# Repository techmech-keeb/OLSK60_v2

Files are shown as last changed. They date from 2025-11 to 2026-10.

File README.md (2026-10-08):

# OLSK60 v2
60% OrthoLinear Keyboard w/ TrackPoint – Designed for Standard Keycap Compatibility

> **この説明はファームウェア v3.0.0 以降向けです。**
> 旧版（v2.x）をお使いの方は、[v2.0.3 時点の説明](https://github.com/techmech-keeb/OLSK60_v2/tree/v2.0.3)をご覧ください。

> **v3.0.0 の公開（2026年10月8日）より前に購入された方へ:** お手元のキーボードには旧版（v2.x）のファームウェアが書き込まれています。**[firmware/README.md](firmware/README.md) の手順で v3 に更新してください。**本リポジトリの説明は v3 を前提にしています。どちらが書き込まれているかわからない場合も、更新して問題ありません（キーボードに保存された設定は初期化されます）。

OLSK60 v2 キーボード外観写真

## 概要
OLSK60 v2は、標準的なキーキャップセットに対応した、60%サイズの格子配列キーボードです。  
トラックポイントを搭載しているため、マウス操作もこの一台で完結します。  
また、GH60互換ケースに対応しており、お好みのキーキャップやケースと自由に組み合わせて、自分だけのカスタマイズを楽しめます。  
見た目も使い心地も、あなた好みに仕上げてください。

> **モデルについて:** 現在販売中のモデルは **v2.1** です。出荷時は **5-Split Space** レイアウトで、同梱のトッププレートに付け替えることで 3-Split Space／6.25U Space にも変更できます。旧モデル **v2** は 3-Split Space および 6.25U Space のみに対応しています。
>
> **ファームウェア（v3）は、機能はどれも同じで、出荷時のキーマップ（プリセット）だけが 2 通り**あります。5-Split Space 用と 3-Split Space 用で、**お使いのトッププレートに合うプリセットを選べば、書き込んだあと調整なしで使えます**。どちらを書き込んでも動作し、キー配置は Vial でいつでも変更できます。

### 主な特徴
- 格子配列60キー
- トラックポイント搭載
- GH60互換ケース対応
- Vial 対応（キーボード定義はファームウェア内蔵）
- 5-Split Space レイアウトで出荷（他のスペース列は対応ファームウェアを書き込んで使用）
- ホットスワップスイッチソケット採用
- スタビライザー実装済み

### 仕様

| 項目 | 内容 |
|---|---|
| 配列 | 直交（格子）配列 60キー、60%サイズ |
| 接続 | USB Type-C |
| MCU | RP2040（UF2 形式でファームウェア書き込み） |
| キーマップ | 5レイヤー、設定ツール（Vial）で編集可能 |
| 同時押し | 6キーまで（標準的な USB キーボードと同じ） |
| ポインティングデバイス | トラックポイント（押し下げクリック対応、オートマウスレイヤー機能） |
| ロータリーエンコーダ | オプション（右上に取り付け可能） |
| LED インジケーター | 1個（レイヤー・設定状態を色で表示） |
| スイッチ | ホットスワップソケット（MX互換） |
| ケース | GH60 互換 |
| キーキャップ | 標準的なキーキャップセットに対応 |

### 出荷時のキー配列（レイヤー0）

OLSK60 レイヤー0（基本レイヤー）のキー配列図

レイヤー構成の詳細は[キーボード操作ガイド](docs/OLSK60_user_guide.md)をご参照ください。

## ドキュメント

> **初めての方へ:** キットを購入された方は、ビルドガイド → キーボード操作ガイド の順にお読みください。

- [ビルドガイド](docs/buildguide.md) — キットの組み立て手順
- [キーボード操作ガイド](docs/OLSK60_user_guide.md) — レイヤー構成・各機能の使い方
- [マウス機能操作マニュアル](docs/OLSK60_mouse_manual.md) — トラックポイントの速度を自分好みに調整する方法
- [FAQ（よくある質問）](docs/faq.md) — モデルの見分け方・設定ツールの選び方など
- [3Dデータ](cad/)
  - [トラックポイントカバー](cad/trackpoint-cover/) - カスタマイズ用のSTEP/STLファイル

## ファームウェア
コンパイル済みファームウェアおよび更新手順は [`firmware/README.md`](firmware/README.md) にて公開しています。

- v3 は **Vial 専用**です（Remap / VIA には対応していません）。
- ファームウェアの**機能は共通**です。ファイルが 2 つあるのは**出荷時のキーマップ（プリセット）の違い**だけで、`5split` / `3split` からお使いのスペース列に合う方を選ぶと、そのまま調整なしで使えます。
- **v3.0.0 の公開（2026年10月8日）より前に購入された方は、v3 に更新してください**（旧版 v2.x が書き込まれています）。

## 購入




| 販売先 | 販売形態 | リンク |
|---|---|---|
| BOOTH | Techmech keys 直営オンラインショップ | [商品ページ](https://techmech.booth.pm/items/5896343) |
| 遊舎工房 | 委託販売（店頭 & オンライン） | [商品ページ](https://shop.yushakobo.jp/products/11324) |

商品に関するお問い合わせは、ご購入先を問わず **Techmech keys** までお願いいたします。

## ライセンス
このプロジェクトは[MITライセンス](LICENSE)の下で公開されています。

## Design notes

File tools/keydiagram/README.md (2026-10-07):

# keydiagram — 操作マニュアル用キー配置図ジェネレータ

`docs/images/` のキー配置図（layer0-base.svg 等）と**完全に同一の様式**で
新しい図を生成するツール。データとスタイルを分離して管理する。

```text
tools/keydiagram/
├─ generate.py        # SVG ジェネレータ（要 python3 + PyYAML）
├─ render_png.mjs     # SVG → PNG(2x) レンダラ（要 Node + Playwright + Chromium）
├─ fetch_fonts.py     # PNG 描画用 Noto Sans JP ウェブフォント取得（初回のみ）
├─ verify_style.py    # 様式回帰テスト（layer0 図をバイト一致で再現できるか）
├─ sync_parts.py      # 共通部品を各図へ複製・検証
├─ parts/
│  └─ mx-switch.svg   # スイッチ正面図の部品マスター
├─ layouts/
│  └─ olsk60.yaml     # 表示レイアウト（キー座標・出荷時刻印）＋ハードウェア注記
└─ diagrams/
   ├─ layer0-base.yaml        # 既存図の再現スペック（回帰テスト基準）
   ├─ piano-mode.yaml         # サウンド機能・ピアノモード音階配置図
   └─ keycap-sizes-*.yaml     # キーキャップサイズガイド（5split/3split/625u）
```

## 使い方

```bash
cd tools/keydiagram
python3 generate.py diagrams/piano-mode.yaml          # SVG を docs/images/ へ
python3 fetch_fonts.py                                # 初回のみ（PNG 用フォント）
python3 generate.py diagrams/piano-mode.yaml --png    # PNG (1936x1000) も生成
python3 verify_style.py                               # 様式回帰テスト
```

## データモデル

3種類の情報を分けて管理する。

1. **表示レイアウト**（`layouts/olsk60.yaml` の `keys:`）
   キーの座標（1u = 60px）・幅・出荷時の刻印。既存図から抽出し、
   製品の物理レイアウト定義と突合済み。
   分割位置（スペース分割・下段オプション）は出荷時キーキャップ構成に統合した
   「表示用」であり、物理マトリクスと 1:1 ではない点に注意。
2. **ハードウェア注記**（同ファイルの `hardware:`）
   TrackPoint マーカーやロータリーエンコーダ凡例など、
   キーマトリクスに現れない要素。
3. **図スペック**（`diagrams/*.yaml`）
   バッジ・タイトル・LED 表示・キーごとの強調/ラベル差し替え・凡例・脚注。
   キーは表示レイアウトの `id` で参照する。

### 図スペックの主な書式

```yaml
layout: olsk60                      # layouts/<name>.yaml を参照
badge: {text: サウンド, color: "#2f66c4"}
title: ピアノモード（音階配置）
note: 右上の補足テキスト
led: {text: 青}                     # 「LED: 」+ 全角テキスト（ドット位置は自動計算）
defaults: base                      # base=出荷時配色 / disabled=全キー薄灰
styles:                             # 図ローカルのキースタイル定義
  white-key: {fill: "#ffffff", stroke: "#2f66c4", label: "#212529", sub: "#868e96"}
keys:                               # id ごとの上書き
  a: {style: white-key, lines: [C4, ド], sub: A}   # lines=2行表示, sub=上部小ラベル
  enter: {style: fx-key, label: Enter, size: 11}   # label=1行表示
encoder:                            # エンコーダ凡例（最大3行＋脚注）
  lines: ["時計回り: ...", "反時計回り: ...", "..."]
  footnote: ※ ...
legend:                             # 下部凡例（row: 2 で2段目、style 省略で文字のみ）
  - {x: 340, style: white-key, text: 白鍵に相当（音階）}
```

### 最下段バリアントとサイズ表示モード

最下段のスペースバー構成（5-Split / 3-Split / 6.25U）は `layouts/olsk60.yaml`
の `variants:` に定義してある（上4段は共通）。図スペックで選択・表示する。

```yaml
variant: 3-split          # 最下段を 3-Split に差し替える（未指定＝5-Split）
label_mode: size          # 全キーに「刻印名（上）＋幅 1.25U（下）」を表示
legend_mode: sizes        # サイズ別の必要数を自動集計して下部に凡例表示
legend_title: ...         # サイズ凡例の見出し（省略可）
legend_footnote: ...      # サイズ凡例の脚注（省略可）
hide_trackpoint: true     # サイズ表では TrackPoint マーカーを隠す
size_palette:             # サイズ→配色（label_mode: size 時に適用）
  1U:    {fill: "#ffffff", stroke: "#c3c9cf"}
  1.25U: {fill: "#dbeafe", stroke: "#4d82c4"}
  # ...
```

`variant` を増やすときは `layouts/olsk60.yaml` の `variants:` に
`replace_y`（差し替える行）とその行のキー一覧を足す。座標の出典は
製品のキーボード定義（レイアウトオプションの選択肢）。

## 共通部品（parts/）

複数の図に登場する部品（キースイッチ等）は `parts/` にマスターを置き、
`sync_parts.py` で各図へ複製する。

```bash
python3 sync_parts.py           # マスターの内容を各図へ反映
python3 sync_parts.py --check   # ズレがないか検証のみ
```

GitHub 上で表示される SVG は外部ファイルを参照できない（`<use href="other.svg#id">`
が効かない）ため、部品は各図にインライン複製する必要がある。複製先は
`<!-- parts:<部品名>:begin -->` 〜 `<!-- parts:<部品名>:end -->` で囲んだ範囲で、
**この中は手で編集しない**（マスターを直して同期する）。

現在の部品:

| 部品 | マスター | 複製先 |
|---|---|---|
| `mx-switch-front` | `parts/mx-switch.svg` | `switch-pins.svg` / `switch-mount.svg` / `build-exploded.svg` |

スイッチ部品の形状は `docs/images/cherry-mx-switch-views.svg`（三面図）の正面図から
取り出したもので、縮尺は **6px = 1mm**。寸法の根拠は
`docs/reference/cherry-mx-switch-spec.md`。ピンは図ごとに描き分けるため部品に含めない
（曲がったピンの図示などに使うため）。

## 様式を変えないためのルール

- ジェネレータや `layouts/olsk60.yaml` を変更したら `verify_style.py` を実行し、
  既存の `docs/images/layer0-base.svg` をバイト一致で再現できることを確認する。
- 新しい配色を増やすときは、既存図のパレット（`generate.py` の `STYLES` と
  既存 diagram の `styles:`）に馴染む色を選ぶ。

## PNG 描画の前提

- Node.js + Playwright（`npm i -g playwright` 済み環境か `npx playwright`）と
  Chromium が必要。ヘッドレス Chromium の `--screenshot` を直接使うと
  ウィンドウ枠ぶんビューポートが欠けるため、Playwright で正確な
  ビューポート（968x500, deviceScaleFactor=2）を指定している。
- 文字は Noto Sans JP。システムに無い環境向けに `fetch_fonts.py` が
  Google Fonts から woff2 を `fonts/`（gitignore 済み）へ取得し、
  レンダラが @font-face で適用する。
- 生成 PNG は既存図と同じ 1936x1000 / 8-bit RGB に正規化される。

## 将来の汎用化メモ

- 他キーボードは `layouts/<name>.yaml` を追加すれば同じ図スペック書式で使える。
  キーボード定義の座標データ（x / y / w）から座標を起こし、
  1u=60px・セル内 3px オフセットで px 化する（`x_px = 3 + 60 * x_u`）。
- 既存の他の図（layer1/2/3 等）も diagram スペック化すれば再生成可能になる。

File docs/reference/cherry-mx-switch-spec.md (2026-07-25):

# Cherry MX スイッチ 寸法リファレンス

単位はすべて mm。元図（Cherry MX データシートの DIMENSIONS / MOUNTING OPTIONS）から読み取った値と、
一般的な MX 互換寸法として補った値を分けて記載する。

| 項目 | 内容 |
|---|---|
| 出典 | Cherry MX データシート（DIMENSIONS / MOUNTING OPTIONS 図）|
| 最終確認日 | 2026-07-24 |
| 用途 | OLSK60 のビルドガイド（スイッチ・プレート・キーキャップの寸法説明）の根拠 |
| 図 | [`../images/cherry-mx-switch-views.svg`](../images/cherry-mx-switch-views.svg)（本書の数値を作図したもの。6px = 1mm）|

> **Status: Reviewed** — §1〜§4 は元図の記載値。§5 と一部の外形値は一般的な MX 互換寸法として補った参考値（§6 参照）。
>
> 「Cherry MX」は Cherry 社の商標。本書は MX 互換スイッチ全般の寸法目安として参照するものであり、
> OLSK60 に特定ブランドのスイッチが同梱・指定されることを意味しない。

## 1. 高さ方向（積み上げ）

| 部位 | 寸法 | 備考 |
|---|---|---|
| ステム突出（ハウジング上面〜ステム頂点） | 3.6 | 未押下時 |
| ハウジング全高 | 11.6 | トップ上面〜ボトム下端 |
| └ うち下部ハウジング（フランジ下面より下） | 5.0 | 11.6 の内訳 |
| ピン突出 | 3.3 | ボトム下端より下 |
| **全高** | **18.5** | 3.6 + 11.6 + 3.3 |

## 2. 外形（XY）

| 項目 | 寸法 |
|---|---|
| トップハウジング フランジ外形 | 15.6 × 15.6 |
| 下部ハウジング（プレート穴に入る部分） | 14.0 × 14.0 |
| プレート開口（推奨） | 14.0 × 14.0 |
| キースイッチピッチ | 19.05 |

## 3. マウント条件

| 項目 | 寸法 | 備考 |
|---|---|---|
| プレート厚 | 1.5 | 0.06 ±0.006 in |
| プレート下面までのハウジング長 | 4.8 | 0.197 +0.012 in |
| プレート上面〜ピン先端 | 約 8.1 | 4.8 + 3.3。元図の「< 8」相当 |
| プレート上面〜ステム頂点 | 約 10.2 | 6.6 + 3.6 |

プレートマウントでは 15.6 のフランジがプレート上面に載り、下部ハウジング側面のラッチが
厚さ 1.5 のプレートに噛む。PCB マウント（5 ピン）はこれに位置決めボスとピンが加わる。

## 4. PCB フットプリント

中央ボス中心を原点 (0, 0) とする。X は右、Y は上（＝上面から見た座標）。

| 穴 | 座標 | 径 |
|---|---|---|
| 中央ボス | (0, 0) | φ4.0 |
| 位置決めボス L | (-5.08, 0) | φ1.7 |
| 位置決めボス R | (+5.08, 0) | φ1.7 |
| 端子 1 | (-3.81, +2.54) | φ1.5 |
| 端子 2 | (+2.54, +5.08) | φ1.5 |

3 ピン（プレートマウント）版では位置決めボス 2 つが省かれる。

## 5. ステム（参考値・元図に記載なし）

| 項目 | 寸法 |
|---|---|
| 十字アーム全長 | 約 4.1 |
| 十字スロット幅 | 約 1.35 |
| ステム外形 | 約 5.5 × 5.5 |
| トラベル（フルストローク） | 4.0 |
| アクチュエーションポイント | 2.0（MX Brown / Blue 等） |

## 6. 注記

- 元図で寸法が明示されているのは §1〜§3 と §4 の座標のみ。
- §5 および「下部ハウジング 14.0」「トップ上面 11.6 角」は一般的な MX 互換寸法として補った値であり、
  厳密な設計に使う場合はメーカー図または実測で確認すること。
- インチ値は元図の併記（0.14 / 0.46 / 0.20 / 0.13 / 0.61 in など）に対応する。

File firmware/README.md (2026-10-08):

# OLSK60 ファームウェア

> **このページはファームウェア v3.0.0 以降の案内です。**
> 旧版（v2.x）の案内は [v2.0.3 時点の説明](https://github.com/techmech-keeb/OLSK60_v2/tree/v2.0.3)をご覧ください。
> ファームウェアは[最新リリース](https://github.com/techmech-keeb/OLSK60_v2/releases/latest)からダウンロードできます。

> **v3.0.0 の公開（2026年10月8日）より前に購入された方へ:** 旧版（v2.x）が書き込まれています。**下の手順で v3 に更新してください。** どちらが書き込まれているかわからない場合も、更新して問題ありません（キーボードに保存された設定は初期化されます）。

このフォルダには OLSK60 キーボードのファームウェアに関する案内が含まれています。
本書ではファームウェアの選び方と書き込み手順を扱います。

> 設定ツールの概要・使い方は、[キーボード操作ガイドの「キーマップのカスタマイズ」](../docs/OLSK60_user_guide.md#キーマップのカスタマイズ)に集約しています。

---

## どのファイルを書き込むか

**ファームウェアの機能はどちらも同じです。**配布ファイルが 2 つあるのは、
**出荷時のキーマップ（プリセット）**が 2 通りあるためで、スペース列ごとに
「書き込んだらそのまま使える」配置を用意しています。

| お使いのスペース列 | そのまま使えるプリセット |
|---|---|
| **5 分割**（v2.1 の出荷時） | `OLSK60_v2_firmware_v<バージョン>_Vial_5split.uf2` |
| **3 分割** | `OLSK60_v2_firmware_v<バージョン>_Vial_3split.uf2` |

**どちらを書き込んでも動作します。**キー配置は Vial でいつでも変更できるので、
あとから好みに合わせて割り当て直すこともできます。

> **プリセットが合っていないとどうなるか:** 例えば 3 分割のキーボードに 5 分割用の
> プリセットを書き込むと、Space が物理キーの無い位置に載るため、そのままでは Space が
> 打てません。**Vial で押せる位置に割り当て直せば、そのまま使えます。** 手間を省きたい
>場合は、最初からお使いのスペース列に合うプリセットを選んでください。
>
> 設定ツール側のレイアウト選択は画面表示の切り替えで、打鍵の割り当ては変わりません。
> 書き込んだ直後の Vial の Layout タブは **3-Split Space** 表示です。5 分割のキーボードでは
> 「5-Split Space」を選び直してください（表示だけの設定で、選び直しは保存されます）。

### 設定ツール

v3 は **Vial 専用**です。**Remap / VIA には対応していません。**
キーボード定義はファームウェアに内蔵されているので、定義ファイルの読み込みは不要です。

---

## 書き込み手順

1. キーボードを PC から取り外します。
2. **ESC キーを押しながら** USB ケーブルを接続します。
3. `RPI-RP2` という名前のドライブが表示されます。
4. ダウンロードした `.uf2` ファイルを、そのドライブにコピーします。
5. コピーが終わるとキーボードが自動的に再起動します。
6. Vial で認識されることを確認してください。

> ファームウェアが起動しない状態でも、**ESC キーを押しながら挿せば**この書き込みモードに入れます。

---

## 書き込む前に

- **書き込むと、キーボードに保存された設定（キー配置・マクロ・トラックポイントの速度など）は
  初期化され、出荷時の状態に戻ります。** v3.0.0-rc.4 以降どうしの書き込みであれば、書き込む前に Vial の
  `Save Current Layout` で保存し、書き込み後に `Load Saved Layout` で読み込み直せます。
- ⚠️ **旧版（v2.x）と、v3.0.0-rc.3 以前のテスト版で保存したレイアウトファイル（`.vil`）は読み込まないでください。**
  独自キー（速度設定・サウンド・オートレイヤーなど）の並びが変わっているため、読み込むと
  **別の機能が割り当てられます**。Vial は保存元のキーボードを確認しないので、そのまま書き込まれます。
  これらから移行する場合は、お手数ですが Vial で組み直してください。
- 書き込み中は USB ケーブルを抜かないでください。
- v3 をお使いで問題がない場合、v3 の新しい版への更新は必須ではありません。

## 元に戻すには

旧版（v2.0.3）に戻す場合は、[v2.0.3 のリリース](https://github.com/techmech-keeb/OLSK60_v2/releases/tag/v2.0.3)から `.uf2` をダウンロードし、
上と同じ手順で書き込めば戻ります（このときも設定は初期化されます）。旧版の使い方は
[v2.0.3 時点の説明](https://github.com/techmech-keeb/OLSK60_v2/tree/v2.0.3)をご覧ください。

---

## v3 の主な変更点

旧版（v2.x）からの主な違いです。

- **設定ツールは Vial のみ**になりました（Remap / VIA 非対応）。
- **スペース列ごとに出荷時キーマップ（プリセット）を用意しました**（上記）。機能の違いはありません。
- **同時に押せるキーは 6 キーまで**です。
- **レイヤーが 5 つになりました。** 自由に使える予備のレイヤー（レイヤー3・初期状態は空き）を追加し、
  マウスレイヤーは一番上のレイヤー4になりました。
- **左親指のキーが Scrl キーになりました。** 押している間は Fn レイヤーがそのまま使え、押しながら
  トラックポイントを動かすとスクロールになります。
- **トラックポイントのスクロールが滑らかになりました。** 1 ノッチより細かい単位で送るため、
  ゆっくり動かしたときの追従が改善します。強く操作するほど速く進む調整も既定で有効です
  （設定レイヤーの `T` で切り替えられます）。
- **設定キー（Delete の右）**: 押している間が設定レイヤー（レイヤー2）です。**短くタップしてから押し続ける**と
  予備のレイヤー（レイヤー3）に入ります。
- **設定レイヤーを作り直しました。** 速度・加速・減速・オートレイヤーの時間は、Q / W / E / V で対象を選び、
  ↑ / ↓ で調整します。配置と操作は[キーボード操作ガイド](../docs/OLSK60_user_guide.md#レイヤー2設定レイヤー)を
  ご覧ください。
- **LED の色と光り方を整理しました。** 緑 = オン・完了、赤 = オフ・受け付けない、黄 = 上限、白 = 通常の状態です。点灯 = レイヤー、ゆっくり明滅 = オートレイヤー中、速い明滅 = 値を調整中で区別します（v3.0.1）。
- **出荷時の設定に戻すキー**（設定レイヤーで 5 を 2 秒押し続ける。キー配置は変わりません）を追加しました。
- **トラックポイントの押し込みクリックをオン / オフ**できるようにしました（設定レイヤーの `G`）。
- **調整枠（速度4・速度5）の基本速度の上限を引き上げました。** トラックポイントの反応が弱いと感じる場合は、
  速度5 を選んで基本速度を上げてお使いください。

詳しい操作は[キーボード操作ガイド](../docs/OLSK60_user_guide.md)と
[マウス機能操作マニュアル](../docs/OLSK60_mouse_manual.md)をご覧ください。

---

## ご報告のお願い

お気づきの点は [Issues](https://github.com/techmech-keeb/OLSK60_v2/issues) へお寄せください。
お使いの OS と、どの操作で起きたかを添えていただけると助かります。
うまくいかないときは [FAQ](../docs/faq.md) もご参照ください。

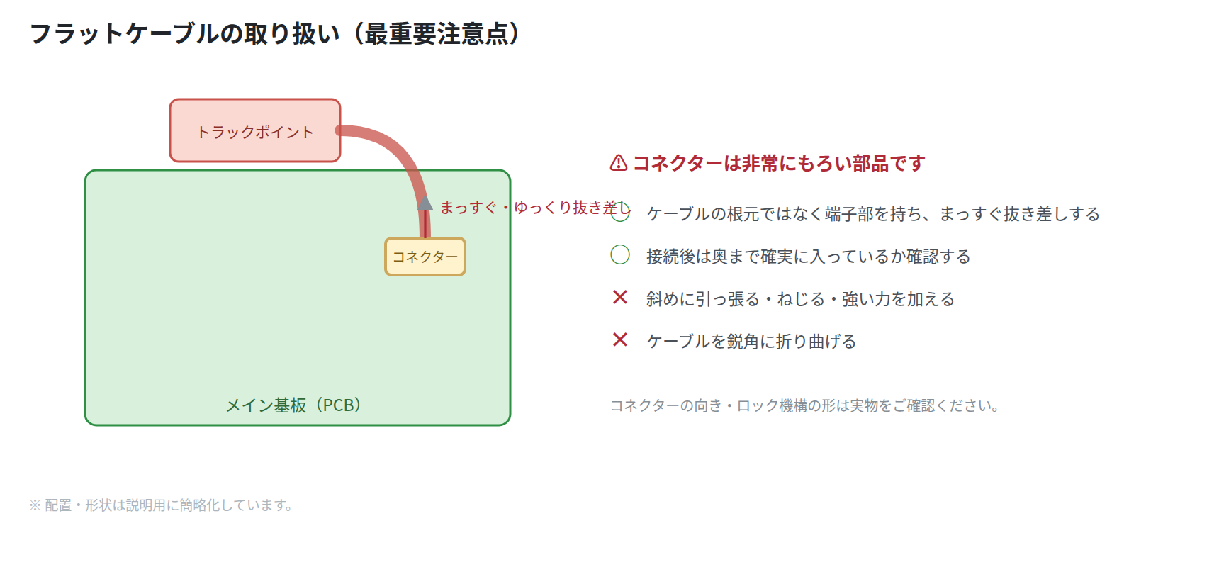
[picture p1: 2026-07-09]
docs/images/flat-cable-handling.png

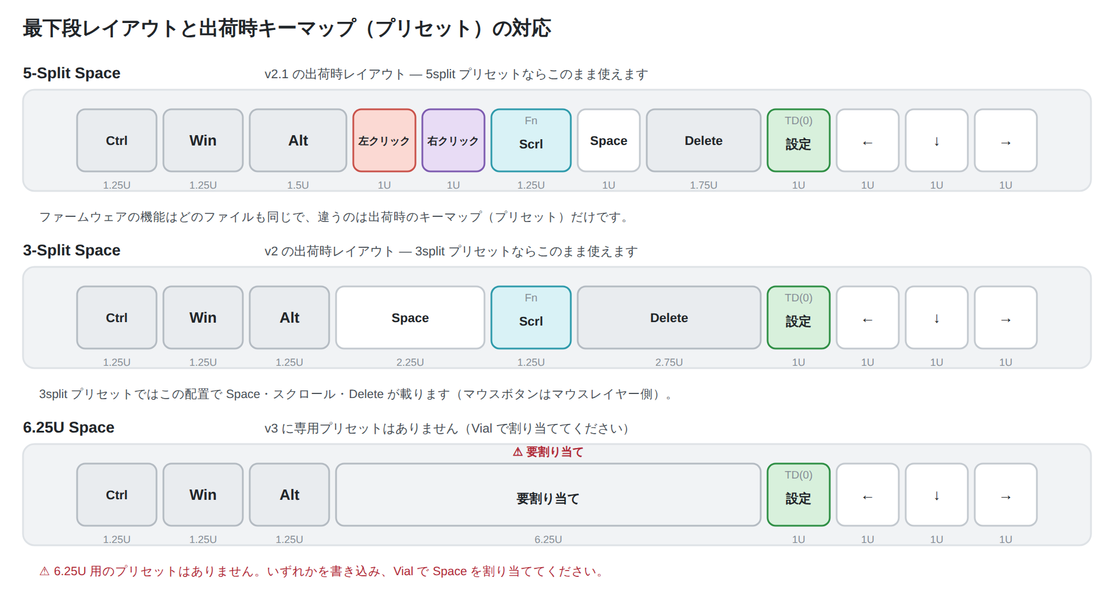
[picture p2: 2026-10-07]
docs/images/bottom-row-options.png

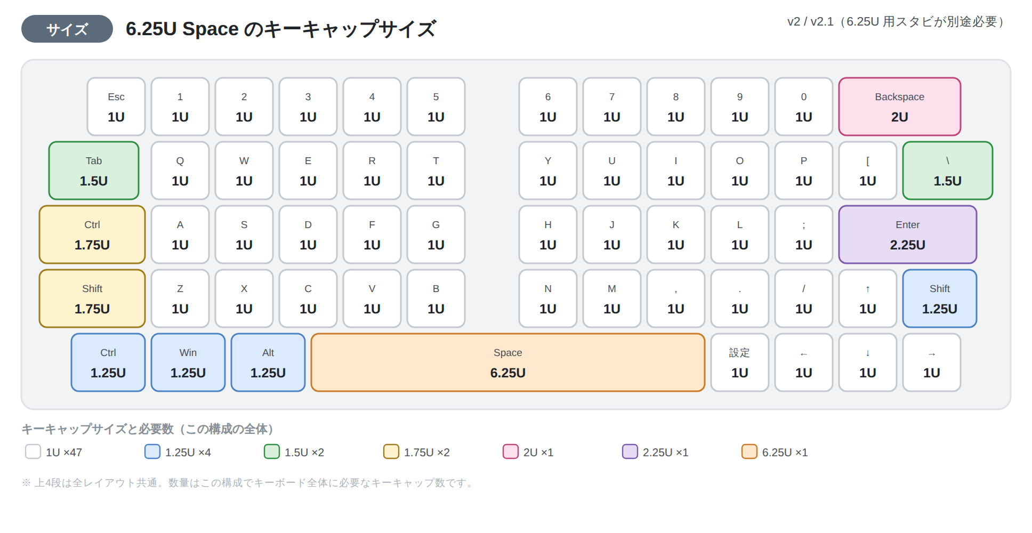
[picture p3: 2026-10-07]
docs/images/keycap-sizes-625u.png

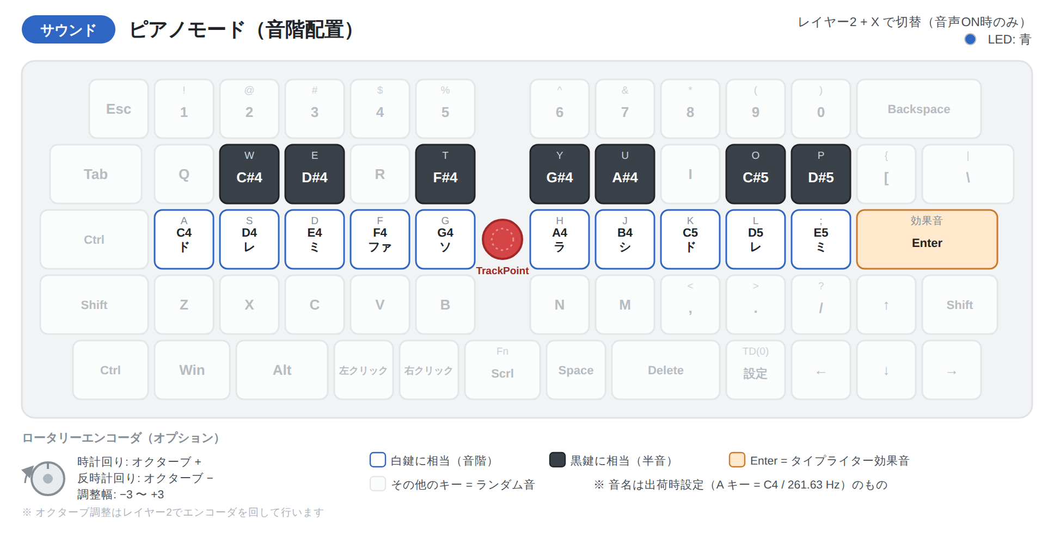
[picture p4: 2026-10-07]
docs/images/piano-mode.png

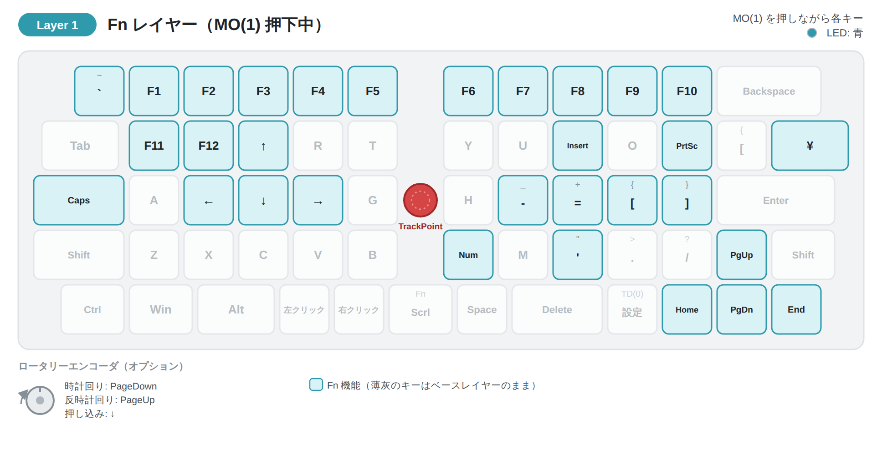
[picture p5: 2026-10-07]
docs/images/layer1-fn.png

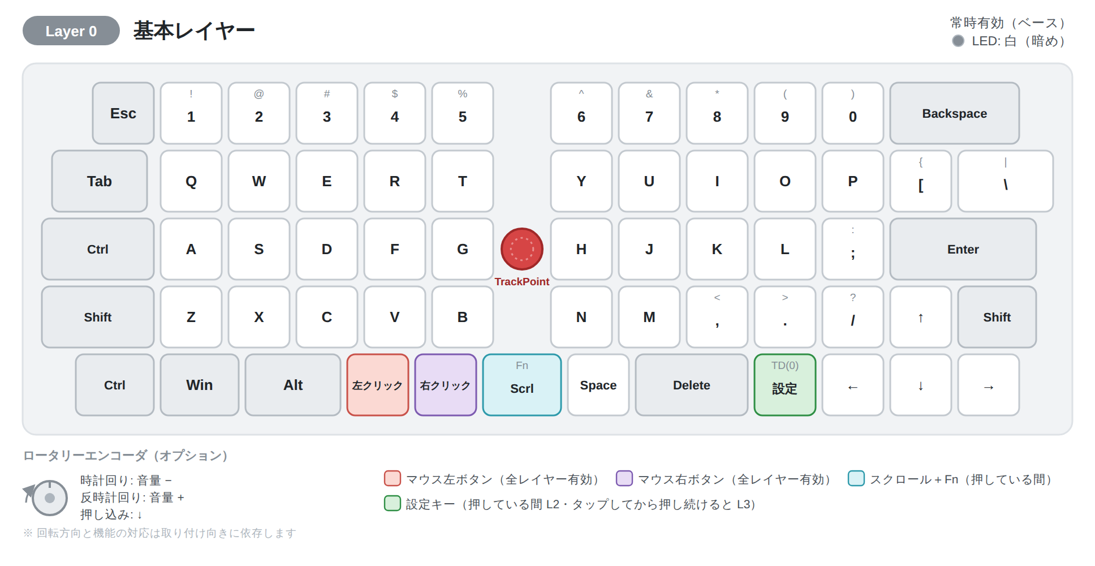
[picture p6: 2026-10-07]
docs/images/layer0-base.png

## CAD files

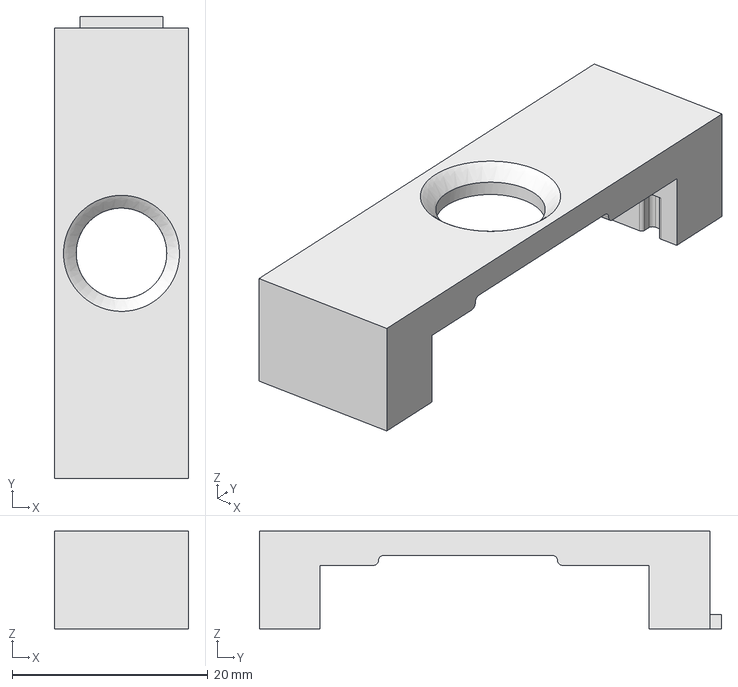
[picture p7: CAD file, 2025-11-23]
cad/trackpoint-cover/OLSK60 TrackPoint Unit ND4.1.step
13.7 x 47.2 x 10.0 mm

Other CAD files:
cad/trackpoint-cover/OLSK60 TrackPoint Unit ND4.1.stl

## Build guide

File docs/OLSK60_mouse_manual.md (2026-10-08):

# OLSK60 マウス機能操作マニュアル

このドキュメントは、OLSK60 v2 のトラックポイント速度設定に関する詳細マニュアルです。トラックポイントの速度を自分好みに微調整したい方を対象としています。  
基本操作や他の機能については[キーボード操作ガイド](OLSK60_user_guide.md)をご参照ください。

> **本書が前提とするファームウェア:** **v3.0.0 以降**（Vial 対応・本リポジトリの[最新リリース](https://github.com/techmech-keeb/OLSK60_v2/releases/latest)）です。旧版（v2.x）をお使いの方は、[v2.0.3 時点の説明](https://github.com/techmech-keeb/OLSK60_v2/tree/v2.0.3)をご覧ください。

---

## クイックリファレンス

すべての操作はレイヤー2（最下段の**設定キー**＝ Delete の右を押しながら）で行います。

| キー | 機能 |
|---|---|
| 1 / 2 | 固定プロファイル切替（速度1 / 速度3） |
| 3 / 4 | 調整枠切替（速度4 / 速度5） |
| Q / W / E | 調整する対象を選ぶ（基本速度 / 加速度 / 減速度） |
| V | 調整する対象を選ぶ（オートレイヤーの解除時間） |
| ← / → | 調整する対象を順に切り替える |
| ↑ / ↓ | 選んだ対象の値を上げる / 下げる（基本速度・加速度・減速度は速度4・速度5 のときのみ） |
| Z | オートレイヤー ON/OFF |
| X / C | オートレイヤー解除時間（150ms / 800ms） |
| T | スクロールの効き方（強く操作するほど速い ⇄ 従来どおり） |
| G | 押し込みクリック ON/OFF |
| . | マウスレイヤーの手動 ON/OFF（TG(4)） |
| 5（2 秒押し続ける） | 出荷時の設定に戻す（キー配置はそのまま） |

---

## 目次

1. [トラックポイントの基本操作](#トラックポイントの基本操作)
2. [速度プロファイル](#速度プロファイル)
3. [調整枠の調整](#調整枠の調整)
4. [オートレイヤー](#オートレイヤー)
5. [LEDリファレンス](#ledリファレンス)
6. [設定の保存](#設定の保存)
7. [トラブルシューティング](#トラブルシューティング)

---

## トラックポイントの基本操作

### カーソル移動

トラックポイントを指先で軽く押すことでカーソルを移動できます。押す力の強さに応じてカーソルの移動速度が変化します。

### マウスボタン

最下段に配置された専用キーで操作します。マウス左ボタン・マウス右ボタンは**レイヤーに関係なく常時有効**です。

| 操作 | キー |
|---|---|
| 左クリック | マウス左ボタン（最下段。3-Split 版はマウスレイヤー側） |
| 右クリック | マウス右ボタン（最下段。3-Split 版はマウスレイヤー側） |

### スクロール

最下段の **Scrl キー**（左親指）を押しながらトラックポイントを動かすと、カーソル移動ではなくスクロール操作になります。押している間は Fn レイヤーも有効です。マウスレイヤーが出ているかどうかに関係なく使えます。

- 上下方向：ページの縦スクロール
- 左右方向：ページの横スクロール

**v3 ではスクロールが細かくなりました。**1 ノッチより小さい単位で送るため、ゆっくり動かしたときの追従が改善します。さらに、**軽く操作したときは細かく、強く操作するほど速く進む**調整が出荷時から有効です。

| 状態 | 切り替え | 動き |
|---|---|---|
| ON（出荷時） | レイヤー2 + T（緑が2回点滅） | 操作の強さで 1 ノッチあたりの送り量が変わります |
| OFF | レイヤー2 + T（赤が2回点滅） | 操作の強さに比例した従来の動きに戻ります |

> ホスト側にもホイール加速がある環境では、二重に加速されて速すぎることがあります。そのときは OFF をお試しください。

### Depress機能（押し下げクリック）

トラックポイントを軽く押し下げることでクリック操作が可能です。出荷時は ON です。レイヤー2 + **G** で ON/OFF を切り替えられます（ON = 緑 / OFF = 赤が2回点滅。設定はキーボード内に保存されます）。

---

## 速度プロファイル

OLSK60 は 5 つの速度プロファイルを備えています。3 つの固定プロファイルと、ユーザーが自由に調整できる 2 つの調整枠です。

### プロファイル一覧

| # | プロファイル名 | 速度の目安 | 編集 |
|---|---|---|---|
| 1 | 速度1（遅い） | 低速（1x） — 細かい操作向け | 不可 |
| 2 | 速度2（中間） | 中速（2x） — 汎用 | 不可 |
| 3 | 速度3（速い）**※デフォルト** | 高速（約3.3x） — 広い画面向け | 不可 |
| 4 | 速度4（調整枠） | 初期値は速度1と同じ | 可能 |
| 5 | 速度5（調整枠） | 初期値は速度3と同じ | 可能 |

速度の倍率は速度1を基準（1x）とした目安です。調整枠は調整後の値がキーボード内に保存されます。

### プロファイルの切り替え

レイヤー2（設定キーを押しながら）で、数字キー1～4を押して切り替えます。

OLSK60 レイヤー2（設定レイヤー）のキー配列図。速度プロファイル選択キーと調整キーが色分けされている

| キー | プロファイル | LED色 |
|---|---|---|
| 1 | 速度1（遅い） | 青 |
| 2 | 速度3（速い） | シアン |
| 3 | 速度4（調整枠） | マゼンタ（赤紫） |
| 4 | 速度5（調整枠） | 橙 |

切り替え時、対応するプロファイル色でLEDが2回点滅します。速度2（中間）は設定レイヤーには置いていません。使いたい場合は、Vial で独自キー「TP Spd2」（色は紫）を好きな位置に割り当ててください。

### 3つのパラメータについて

| パラメータ | 効果 |
|---|---|
| 基本速度 | カーソル移動の全体的な速さ。大きいほど速い |
| 加速度 | トラックポイントを強く押した時の速度の増加率 |
| 減速度 | トラックポイントから力を抜いた時の速度の減衰率 |

---

## 調整枠の調整

速度4と速度5は、3つのパラメータを個別に調整できるプロファイルです。

> ⚠️ **重要:** 基本速度・加速度・減速度は、速度4 または速度5 を選択中のみ調整できます。速度1・速度3 を選択中は LED が**赤く速く3回**点滅し、操作は受け付けられません。上限・下限に達しているときは **黄色く速く3回**点滅します。

### 調整手順

1. レイヤー2で「3」（速度4）または「4」（速度5）を押し、調整枠を選択します（対応色でLEDが2回点滅）。
2. 設定キーを押したまま、調整したいパラメータを選びます。LED がその色で速く明滅します。

   | キー | 対象 | 明滅の色 |
   |------|------|---------|
   | Q | 基本速度 | 青 |
   | W | 加速度 | シアン |
   | E | 減速度 | 紫 |

   ← / → で順に切り替えることもできます。
3. **↑** で 1 段上げ（長めに1回光る）、**↓** で 1 段下げ（短く2回光る）ます。
4. 設定キーを離すと調整は終わります。値は自動保存されるので、そのまま使い始められます。

### 調整の範囲

各パラメータには上限と下限があり、限界値に達するとそれ以上の調整は反映されません（黄が速く3回点滅）。

| パラメータ | 下限から上限までのステップ数（目安） |
|---|---|
| 基本速度 | 約46ステップ |
| 加速度 | 約15ステップ |
| 減速度 | 約30ステップ |

基本速度は、速度1 のおよそ 8 倍（速度3 のおよそ 2.4 倍）まで上げられます。トラックポイントの反応が弱いと感じる場合は、速度5 を選んで基本速度を上げてください。ただし、速度を上げるほど、ゆっくり動かしたときの最小の移動量も大きくなります（細かい位置合わせはしにくくなります）。

### 使い方の例

2つの調整枠にそれぞれ異なるチューニングを保存し、作業に応じて切り替えて使えます。

- **速度4** → 画像編集やCADなど精密な操作用に、基本速度を低くし減速度を高めに設定
- **速度5** → マルチディスプレイ環境用に、基本速度と加速度を高めに設定

---

## オートレイヤー

トラックポイントを操作すると、自動的にレイヤー4（マウスレイヤー）に切り替わる機能です。詳しい動作の仕組みは[キーボード操作ガイドのオートレイヤーセクション](OLSK60_user_guide.md#オートレイヤー機能)をご参照ください。

### 解除タイミングの調整

レイヤー2で、トラックポイント操作停止後にマウスレイヤーが解除されるまでの時間を選べます。

| キー | 設定 | 遅延時間 | LED | 用途 |
|---|---|---|-----|---|
| X | 短い | 150ms | 橙が1回点滅 | キー入力を優先したい場合 |
| C | 長い **※デフォルト** | 800ms | 橙が3回点滅 | マウス操作を優先したい場合 |
| V → ↑ / ↓ | 好みの時間 | 100〜2000ms（10ms 刻み） | 橙で速く明滅 | 細かく合わせたい場合 |

V で対象を「解除時間」にすると、速度プロファイルに関係なく ↑ / ↓ で調整できます。中間の 400ms は Vial の独自キー「AL 400」でも選べます。

### オートレイヤーの ON/OFF

レイヤー2 + Z キーで機能自体を切り替えられます。

| 状態 | LED表示 |
|---|---|
| ON | 緑が2回点滅 |
| OFF | 赤が2回点滅 |

OFFにしても、トラックポイントのカーソル移動・マウスボタン・**Scrl キーでのスクロール**は通常どおり使えます。マウスレイヤーを手動で出したいときは、レイヤー2の **「.」キー**（TG(4)）で ON/OFF できます。

---

## LEDリファレンス

**色の約束:** 緑 = オン・完了、赤 = オフ・受け付けない、黄 = 上限・下限、白 = 通常の状態。この4色はその意味にだけ使い、ほかの色はレイヤーや選んでいる項目を表します。**光り方**でも区別します: 点灯 = レイヤー、ゆっくり明滅 = オートレイヤー中、速い明滅 = 設定レイヤーで値を調整中、短い点滅 = 設定を変えた合図。

### 速度プロファイルの色

マウスレイヤーがトラックポイント操作で自動的に有効になっている間、選択中のプロファイルに応じた色でゆっくり明滅します。手動（「.」キー）で有効にしたときは、マゼンタ（赤紫）で点灯します。

| プロファイル | LED色 |
|---|---|
| 速度1（遅い） | 青 |
| 速度2（中間） | 紫 |
| 速度3（速い） | シアン |
| 速度4（調整枠） | マゼンタ（赤紫） |
| 速度5（調整枠） | 橙 |

### 設定操作時のフィードバック

| 操作 | LED表示 |
|---|---|
| プロファイル変更 | 対応色が2回点滅 |
| 調整する対象を選ぶ（Q / W / E / V、← / →） | 対象の色で速く明滅（基本速度 = 青 / 加速度 = シアン / 減速度 = 紫 / 解除時間 = 橙） |
| 値を上げる（↑） | 対象の色で長めに1回光る |
| 値を下げる（↓） | 対象の色で短く2回光る |
| 上限・下限に達した | 黄が速く3回点滅 |
| 操作を受け付けない（速度1・速度3 のときの調整） | 赤が速く3回点滅 |
| オートレイヤー解除時間 150ms / 800ms | 橙が1回 / 3回点滅 |
| オートレイヤー ON / OFF | 緑 / 赤が2回点滅 |
| スクロールの効き方 ON / OFF | 緑 / 赤が2回点滅 |
| 押し込みクリック ON / OFF | 緑 / 赤が2回点滅 |
| 出荷時の設定に戻した（5 を 2 秒） | 緑がゆっくり3回点滅 |

---

## 設定の保存

- 速度プロファイルの選択、調整枠のパラメータ、オートレイヤーの設定、スクロールの効き方、押し込みクリックの ON/OFF は、自動的にキーボード内へ保存されます。
- キーボードの電源を切っても設定は保持されます。
- レイヤー2の **5 を 2 秒押し続ける**と、これらの設定が出荷時の状態に戻ります（キー配置はそのまま）。
- レイヤー2の **9**（設定の全消去）を実行すると、キー配置も含めてすべて工場出荷状態に戻ります。
- **ファームウェアを書き込み直したときも初期化されます。**

---

## トラブルシューティング

### カーソルが動かない

1. USBケーブルを抜き差しして再起動してください。
2. トラックポイントのフラットケーブルが正しく接続されているか確認してください（[ビルドガイド](buildguide.md)参照）。

### カーソル速度が合わない

1. レイヤー2で速度プロファイルを切り替えて試してください（1～4キー）。
2. 固定プロファイルで好みに近いものを見つけてから、調整枠（速度4・速度5）で微調整するのがおすすめです。
3. 速度3 でも遅い・反応が弱いと感じる場合は、速度5 を選び、Q → ↑ で基本速度を上げてください。

### 調整ができない（赤3回点滅）

固定プロファイル（速度1・速度3）が選択されています。レイヤー2で「3」（速度4）または「4」（速度5）を押して調整枠に切り替えてから調整してください。

### それ以上上がらない（黄3回点滅）

上限（または下限）に達しています。

### スクロールが効かない

1. 最下段の **Scrl キー**（左親指）を押しながらトラックポイントを操作してください。マウスレイヤーが出ているかどうかは関係ありません。
2. 3-Split 版では最下段の並びが異なります。Scrl キーは Space（2.25U）の右隣です。

### スクロールが速すぎる / 細かすぎる

レイヤー2 + **T** で、スクロールの効き方を切り替えられます（緑 = 強く操作するほど速い、赤 = 従来どおり）。

### 設定をリセットしたい

レイヤー2 + **5 を 2 秒押し続ける**と、トラックポイントやオートレイヤーなどの設定が出荷時の状態に戻ります（キー配置はそのまま）。キー配置も含めて工場出荷状態にしたい場合は、レイヤー2 + **9**（設定の全消去）を実行してください。

---

## サポート

ご不明点があれば [BOOTHの商品ページ](https://techmech.booth.pm/items/5896343) または [GitHub Issue](https://github.com/techmech-keeb/OLSK60_v2/issues) にてご連絡ください。

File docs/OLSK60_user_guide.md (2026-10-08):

# OLSK60 キーボード操作ガイド

このドキュメントは、OLSK60 v2 シリーズ（v2 / v2.1）の操作方法を総合的にまとめたものです。  
トラックポイントの詳細な速度設定については、[マウス機能操作マニュアル](OLSK60_mouse_manual.md)もあわせてご参照ください。

> **本書が前提とするファームウェア:** 本書は**ファームウェア v3.0.0 以降**の出荷時キーマップを説明しています。旧版（v2.x）をお使いの方は、[v2.0.3 時点の説明](https://github.com/techmech-keeb/OLSK60_v2/tree/v2.0.3)をご覧ください。入手と書き込みは [firmware/README.md](../firmware/README.md) をご参照ください。
>
> 旧版（v2.x）からの主な違い: **設定ツールは Vial のみ**（Remap / VIA 非対応）、**スペース列ごとに出荷時キーマップ（プリセット）を用意**、**同時に押せるキーは 6 キーまで**。

---

## クイックスタート

OLSK60 v2 を初めて使う方は、まずこのセクションをお読みください。

1. **接続:** USBケーブル（Type-C）でPCに接続します。LEDが白く点灯すれば正常です。
2. **基本入力:** レイヤー0（基本レイヤー）で通常のキー入力ができます。
3. **ファンクションキー:** 最下段の **Scrl キー**（左親指・Fn 兼用）を押しながら数字キーを押すと、F1〜F10 が入力できます。
4. **マウス操作:** トラックポイントを指先で軽く押してカーソルを移動。最下段のマウスボタンでクリックできます。
5. **スクロール:** 最下段の **Scrl キー**（左親指・Fn と兼用）を押しながらトラックポイントを動かすとスクロールになります。
6. **設定変更:** 最下段の**設定キー**（Delete の右）を押しながら操作すると、トラックポイント速度や音声などの設定を変更できます。

---

## 目次

1. [はじめに](#はじめに)
2. [レイヤー構成の全体像](#レイヤー構成の全体像)
3. [レイヤー0：基本レイヤー](#レイヤー0基本レイヤー)
4. [レイヤー1：Fnレイヤー](#レイヤー1fnレイヤー)
5. [レイヤー2：設定レイヤー](#レイヤー2設定レイヤー)
6. [レイヤー3：予備レイヤー](#レイヤー3予備レイヤー)
7. [レイヤー4：マウスレイヤー](#レイヤー4マウスレイヤー)
8. [トラックポイントの基本操作](#トラックポイントの基本操作)
9. [オートレイヤー機能](#オートレイヤー機能)
10. [音声フィードバック機能](#音声フィードバック機能)
11. [ロータリーエンコーダ](#ロータリーエンコーダ)
12. [LEDインジケーター](#ledインジケーター)
13. [キーマップのカスタマイズ](#キーマップのカスタマイズ)
14. [特殊操作](#特殊操作)
15. [トラブルシューティング](#トラブルシューティング)

---

## はじめに

### キーボードの接続

1. USBケーブル（Type-C）をキーボードに接続します。
2. コンピューターのUSBポートに接続します。
3. キーボードが自動的に認識され、LEDが白く点灯すれば正常です。

### キーボードの基本構成

OLSK60 v2 は直交配列（格子配列）の60%キーボードです。

- 60キーの直交配列
- トラックポイントを中央に搭載
- 5つのレイヤーによるキーマップ切り替え
- ロータリーエンコーダ（オプション）
- LEDインジケーター（1個）

### ファームウェアと設定ツール

キーマップの編集には **Vial** を使います（詳しくは[キーマップのカスタマイズ](#キーマップのカスタマイズ)を参照）。ファームウェアの選び方・書き込み手順は [firmware/README.md](../firmware/README.md) をご参照ください。

---

## レイヤー構成の全体像

OLSK60 は 5 つのレイヤーを持ち、それぞれ異なる役割を担っています。

| レイヤー | 名称 | 切り替え方法 | LED色 |
|---|---|---|---|
| レイヤー0 | 基本レイヤー | 常時有効（ベース） | 白（暗め） |
| レイヤー1 | Fnレイヤー | Scrl キー（左親指）を押している間 | 青 |
| レイヤー2 | 設定レイヤー | 設定キー（Delete の右）を押している間 | 橙（値の調整中は対象の色で速く明滅） |
| レイヤー3 | 予備レイヤー | 設定キーを短くタップしてから押し続けている間（初期状態は空き） | シアン |
| レイヤー4 | マウスレイヤー | トラックポイント操作時に自動、またはレイヤー2の「.」キー（TG(4)）で手動 | 自動時は速度プロファイルの色でゆっくり明滅、手動時はマゼンタ（赤紫）で点灯 |

レイヤーは番号が大きいほど優先されます。レイヤー0は常にベースとして機能し、他のレイヤーがオフの場合に使用されます。

### レイヤーの切り替え方式

OLSK60 では**モーメンタリー方式（MO）**を採用しています。キーを押している間だけレイヤーが有効になり、離すと元のレイヤーに戻ります。レイヤー4（マウスレイヤー）だけは例外で、トラックポイント操作で自動的に有効になり、操作をやめると設定時間後に解除されます（レイヤー2の「.」キーで手動 ON/OFF も可能）。

---

## レイヤー0：基本レイヤー

レイヤー0は通常の入力に使用する基本レイヤーです。標準的な60%キーボードに近い配置を直交配列で実現しています。

OLSK60 レイヤー0（基本レイヤー）のキー配列図

### 最上段

| 位置 | キー |
|---|---|
| 左端 | Esc |
| 数字列 | 1～0 |
| 右端 | Backspace（2U） |

### 2段目

| 位置 | キー |
|---|---|
| 左端 | Tab（1.5U） |
| 文字列 | Q W E R T ／ Y U I O P [ |
| 右端 | \（1.5U） |

### 3段目

| 位置 | キー |
|---|---|
| 左端 | Ctrl（1.75U） |
| 文字列 | A S D F G ／ H J K L ; |
| 右端 | Enter（2.25U） |

### 4段目

| 位置 | キー |
|---|---|
| 左端 | Shift（1.75U） |
| 文字列 | Z X C V B ／ N M , . / |
| 右端 | ↑, Shift（1.25U） |

### 最下段（5-Split-Spaceレイアウトの場合）

> **注意:** 以下の最下段配列は、v2.1の出荷時（デフォルト）レイアウトである 5-Split-Space 版ファームウェアの場合です。3-Split-Space 版は並びが異なります（[スペースバーのレイアウトオプション](#スペースバーのレイアウトオプション)参照）。

左から順に：

| キー | サイズ | 説明 |
|---|---|---|
| Ctrl | 1.25U | 左Ctrl |
| Win | 1.25U | 左Win/Cmd |
| Alt | 1.5U | 左Alt |
| マウス左ボタン | 1U | 常にマウス左クリックとして動作 |
| マウス右ボタン | 1U | 常にマウス右クリックとして動作 |
| Scrl（Fn） | 1.25U | 押している間 **トラックポイントがスクロールになり、同時にレイヤー1（Fn）も有効**になります |
| Space | 1U | スペースキー |
| Delete | 1.75U | Deleteキー |
| 設定キー | 1U | 押している間レイヤー2（設定）に切り替え。短くタップしてから押し続けるとレイヤー3（予備） |
| ← | 1U | カーソルキー左 |
| ↓ | 1U | カーソルキー下 |
| → | 1U | カーソルキー右 |

**マウス左ボタン・マウス右ボタンは、レイヤーに関係なく常にマウスボタンとして動作します。** トラックポイントでカーソルを動かしながら、親指で左右クリックを行えます。

> **Scrl キーについて:** 従来の Fn キー（MO(1)）の位置が、v3 では **Scrl キー**になりました。押している間は Fn レイヤーが有効になるので **Fn の機能はそのまま使えます**。加えて、押しながらトラックポイントを動かすとスクロールになります。

### スペースバーのレイアウトオプション

**ファームウェア（v3）は、機能はどれも同じです。**配布ファイルが 2 つあるのは、**出荷時のキーマップ（プリセット）**が 2 通りあるためで、スペース列ごとに「そのまま使える」配置を用意しています。**どちらを書き込んでも動作し**、キー配置は Vial でいつでも変更できます。

| オプション | 構成 | 対応モデル | そのまま使えるプリセット |
|---|---|---|---|
| 5-Split-Space | 1U、1U、1.25U、1U、1.75Uの5キー構成 | **v2.1のみ**（v2.1のデフォルト） | `..._Vial_5split.uf2` |
| 3-Split-Space | 2.25U、1.25U、2.75Uの3キー構成 | v2 / v2.1（v2のデフォルト） | `..._Vial_3split.uf2` |
| 6.25U Space | 標準的な6.25Uスペースバー | v2 / v2.1 | 専用プリセットはありません（いずれかを書き込み、Vial で割り当ててください） |

> **注意:** 5-Split-Spaceレイアウトはv2.1でのみ選択可能です。v2.1は出荷時に5-Split-Spaceで構成されています。v2の基板はこのレイアウトに対応していません。お手持ちのモデルがv2かv2.1か不明な場合は、基板上のシルク印刷をご確認ください。

以下の図は、各レイアウトオプションに出荷時キーマップのキーがどう対応するかを示しています。

最下段レイアウト（5-Split / 3-Split / 6.25U）と、書き込むファームウェアファイルの対応図

> **プリセットが合っていないとどうなるか:** 例えば 3-Split のキーボードに 5-Split 用のプリセットを書き込むと、Space が**物理キーの無い位置**に載るため、そのままでは Space が打てません。壊れているわけではなく、**Vial で Space を押せる位置に割り当て直せばそのまま使えます**。手間を省きたい場合は、最初からお使いのスペース列に合うプリセットを選んでください。

> **3-Split 版のキー配置:** 最下段は左から Ctrl / Win / Alt / **Space（2.25U）** / **Scrl（1.25U）** / **Delete（2.75U）** / 設定キー / ←↓→ です。**マウス左右ボタンは最下段ではなくマウスレイヤー側**（トラックポイント操作中）に載ります。

> **設定ツールのレイアウト表示について:** Vial のレイアウトオプションは**画面に表示するキーの形**を切り替えるだけで、打鍵の割り当ては変わりません。書き込んだ直後の表示は **3-Split** です。5-Split のキーボードでは、Vial の Layout タブで 5-Split を選び直してください（表示だけの設定で、選び直した内容は保存されます）。

> 💡 各レイアウトで**どのサイズのキーキャップが何個必要か**は、ビルドガイドの[キーキャップサイズガイド](buildguide.md#31-キーキャップサイズガイド)にレイアウト別の図と数量表を用意しています。

---

## レイヤー1：Fnレイヤー

最下段の **Scrl キー**（左親指）を押している間、有効になります。ファンクションキーやカーソル移動関連のキーが配置されています。レイヤー0とレイヤー1を合わせて、概ねテンキーレスキーボード相当のキーをカバーしています。

OLSK60 レイヤー1（Fnレイヤー）のキー配列図

> 図中の薄いグレーのキーはレイヤー0と同じ動作です（以降のレイヤー図も同様）。

### 主な変更点

| キー位置 | レイヤー0 | レイヤー1 |
|---|---|---|
| 最上段左端 | Esc | ` (グレイヴ) |
| 数字列 | 1～0 | F1～F10 |
| Q / W | Q / W | F11 / F12 |
| E / S / D / F | 文字 | ↑ / ← / ↓ / →（カーソル） |
| I | I | Insert |
| P | P | Print Screen |
| CapsLock位置 | Ctrl | Caps Lock |
| J / K / L | 文字 | - / = / [ |
| ; | ; | ] |
| 右端（2段目） | \ | ¥ |
| ↑ / ↓ | ↑ / ↓ | Page Up / Page Down |
| ← / → | ← / → | Home / End |

---

## レイヤー2：設定レイヤー

最下段の**設定キー**（Delete の右）を押している間、有効になります。トラックポイントの速度、オートレイヤー、音声などの設定と、本体の操作（書き込みモード・再起動）を行うレイヤーです。設定キーを押したまま、各キーを押してください。

OLSK60 レイヤー2（設定レイヤー）のキー配列図。設定キーが機能ごとに色分けされている

> **設定キーの 2 つの使い方:** 押し続けると設定レイヤー（LED 橙）になります。**短くタップしてから、すぐに押し続ける**と予備のレイヤー（[レイヤー3](#レイヤー3予備レイヤー)）になります。単独で押し続けたときは、LED が橙になるまでわずかに間があります（他のキーと一緒に押せば待ち時間はありません）。

### トラックポイント速度プロファイル選択（数字列）

| キー | 機能 | LED |
|---|---|-----|
| 1 | 速度1（遅い・固定） | 青が2回点滅 |
| 2 | 速度3（速い・固定）**※デフォルト** | シアンが2回点滅 |
| 3 | 速度4（調整枠） | マゼンタ（赤紫）が2回点滅 |
| 4 | 速度5（調整枠） | 橙が2回点滅 |

速度2（中間）は設定レイヤーには置いていません。使いたい場合は、Vial で独自キー「TP Spd2」（色は紫）を好きな位置に割り当ててください。プロファイルの詳細は[マウス機能操作マニュアル](OLSK60_mouse_manual.md)をご参照ください。

### 値の調整（Q / W / E / V と矢印キー）

調整したい**対象**を選んでから、**↑ / ↓** で値を増減します。対象を選ぶと、LED がその対象の色で速く明滅します。

| キー | 機能 | 明滅の色 |
|---|---|---|
| Q | 対象を「基本速度」にする | 青 |
| W | 対象を「加速度」にする | シアン |
| E | 対象を「減速度」にする | 紫 |
| V | 対象を「オートレイヤーの解除時間」にする | 橙 |
| ← / → | 対象を順に切り替える（基本速度 → 加速度 → 減速度 → 解除時間） | 対象の色 |
| ↑ | 選んだ対象の値を 1 段上げる | 対象の色で長めに 1 回光る |
| ↓ | 選んだ対象の値を 1 段下げる | 対象の色で短く 2 回光る |

- 基本速度・加速度・減速度は、**速度4 または速度5 を選んでいるときだけ**調整できます。速度1・速度3 のときは LED が**赤く速く3回**点滅し、操作は受け付けられません。
- 上限・下限に達すると、LED が**黄色く速く3回**点滅します。
- オートレイヤーの解除時間は、どの速度プロファイルでも 10 ms 刻みで調整できます。
- 設定キーを離すと、対象は「基本速度」に戻ります。調整した値は自動で保存されます。

### オートレイヤー（Z / X / C）

| キー | 機能 | LED |
|---|---|-----|
| Z | オートレイヤー ON/OFF | ON = 緑 / OFF = 赤が2回点滅 |
| X | 解除時間を短く（150ms） | 橙が1回点滅 |
| C | 解除時間を長く（800ms）**※デフォルト** | 橙が3回点滅 |

中間の 400ms は Vial の独自キー「AL 400」で選べます。V と ↑ / ↓ を使えば 10 ms 刻みで好みの時間にできます。

### トラックポイントの切り替え（T / G）

| キー | 機能 | LED |
|---|---|-----|
| T | スクロールの効き方の切り替え。**ON**: 軽く操作したときは細かく、強く操作するほど速く進みます（出荷時）。**OFF**: 操作の強さに比例した従来の動きに戻ります | ON = 緑 / OFF = 赤が2回点滅 |
| G | トラックポイントの押し込みクリック（Depress 機能）の ON/OFF（出荷時は ON） | ON = 緑 / OFF = 赤が2回点滅 |

> ホストによってはスクロールの加速が二重にかかることがあります。速すぎると感じたら T で OFF をお試しください。

### 音声設定（A / S）

| キー | 機能 | LED |
|---|---|-----|
| A | 全音声 ON/OFF | ON = 緑 / OFF = 赤が2回点滅 |
| S | サウンドモード切替（ランダム ↔ ピアノ） | ピアノ = 青 / ランダム = 橙が2回点滅 |

### 本体の操作

| キー | 機能 | 説明 |
|---|---|---|
| 5 | 出荷時の設定に戻す | **押し続けて 2 秒**で、速度・調整枠・オートレイヤー・スクロールの効き方・押し込みクリック・音声の設定を出荷時に戻します（緑がゆっくり3回点滅）。**キー配置は変わりません。**2 秒経つ前に離すと取り消されます |
| . | マウスレイヤーの手動 ON/OFF | Vial 上の表示は `TG(4)`。キーを離したときに切り替わります（ON の間 LED はマゼンタ） |
| 9 | 設定の全消去 | 保存されているキー配置と設定をすべて消去し、工場出荷状態に戻します |
| 0 | 書き込みモード（BOOTSEL） | ファームウェア書き込み用のモードで再起動します |
| Backspace | 再起動 | キーボードを再起動します |

> ⚠️ **注意:** 9（設定の全消去）は、Vial で変更したキー配置も含めてすべて初期化します。設定だけを戻したいときは 5（出荷時の設定に戻す）を使ってください。

---

## レイヤー3：予備レイヤー

**初期状態では何も割り当てられていない、自由に使えるレイヤー**です（すべてのキーがレイヤー0と同じ動作）。Vial で好きなキーを割り当てて使います。

- **入り方:** 設定キーを**短くタップしてから押し続ける**と、押している間だけ有効になります（LED シアン）。Vial で `MO(3)` や `TG(3)` を割り当てることもできます。
- **スクロールしながら使う:** Vial の独自キー「Scrl L3」を割り当てると、押している間スクロールになり、同時にレイヤー3が有効になります。
- このレイヤーを使っている間は、オートレイヤー（マウスレイヤーへの自動切り替え）は働きません。

---

## レイヤー4：マウスレイヤー

トラックポイントの操作時に自動的に有効になるレイヤーです（オートレイヤー機能）。一番上のレイヤーなので、他のレイヤーの上に重なります。

OLSK60 レイヤー4（マウスレイヤー）のキー配列図

### レイヤー0からの主な変更点

レイヤー4では、ほとんどのキーはレイヤー0と同じですが、一部が変わります。

| キー位置 | レイヤー0 | レイヤー4 |
|---|---|---|
| Esc の位置 | Esc | マウスレイヤーを抜ける（TO(0)） |
| W / A / S / D | 文字 | ホイール ↑ / ← / ↓ / → |
| I / J / K / L | 文字 | カーソル ↑ / ← / ↓ / → |
| マウス左・右ボタンの位置 | マウス左・右ボタン | 同じ（左・右クリック） |
| Scrl の位置 | スクロール＋Fn | マウス中ボタン（5-Split の場合） |
| 設定キーの位置 | 設定レイヤー | マウスレイヤーを抜ける（TO(0)） |

> **3-Split 版**では最下段の並びが変わり、レイヤー4では左から **マウス左ボタン / スクロール / マウス右ボタン**になります。

**スクロールしたいとき**は、最下段の **Scrl キー**を押しながらトラックポイントを動かします（マウスレイヤーが有効かどうかに関わらず使えます）。上下だけでなく左右のスクロールもできます。

> Vial の独自キー「Scrl Ms」を割り当てると、押している間スクロールになり、同時にマウスレイヤーが有効になります（出荷時は未配置）。

---

## トラックポイントの基本操作

### カーソル移動

トラックポイントを指先で軽く押すことでカーソルを移動できます。押す力の強さに応じてカーソルの移動速度が変化します。

### マウスボタン

最下段に配置された専用キーで操作します。

| 操作 | キー | 備考 |
|---|---|---|
| 左クリック | マウス左ボタン | レイヤーに関係なく常時有効（3-Split 版はマウスレイヤー側） |
| 右クリック | マウス右ボタン | レイヤーに関係なく常時有効（3-Split 版はマウスレイヤー側） |
| スクロール | Scrl キー（最下段・左親指） | 押している間、トラックポイントの動きがスクロールになります |

### スクロール操作

最下段の **Scrl キー**を押しながらトラックポイントを動かすと、カーソル移動ではなくスクロール操作になります。押している間は Fn レイヤーも有効です。

- 上下方向：ページの縦スクロール
- 左右方向：ページの横スクロール

**v3 ではスクロールが滑らかになりました。**1 ノッチより細かい単位で送るため、ゆっくり動かしたときの追従が改善します。また、**軽く操作したときは細かく、強く操作するほど速く進む**調整が出荷時から有効です。従来の動きに戻したい場合は、レイヤー2の **T キー**で切り替えてください。

### Depress機能（トラックポイント押し下げクリック）

トラックポイントを軽く押し下げることでクリック操作が可能です。出荷時は ON です。誤ってクリックしてしまう場合は、レイヤー2の **G キー**で OFF にできます（ON = 緑 / OFF = 赤が2回点滅。設定はキーボード内に保存されます）。

---

## オートレイヤー機能

トラックポイントを操作すると、自動的にレイヤー4（マウスレイヤー）に切り替わります。マウス中ボタンなどが使えるようになり、W/A/S/D・I/J/K/L でホイールとカーソルも操作できます。

### 動作の流れ

1. トラックポイントを動かすと、レイヤー4が自動的に有効になります。
2. トラックポイントの操作を停止すると、設定した時間の経過後にレイヤー4が自動的に解除されます。
3. マウスボタンや Scrl キーを押している間は、レイヤー4が維持されます。
4. レイヤー1・レイヤー2・レイヤー3を使っている間は、自動では切り替わりません。

### 解除タイミングの調整

レイヤー2で、オートレイヤーが解除されるまでの時間を選べます。

| 操作 | 遅延時間 | LED | 用途 |
|---|---|-----|---|
| レイヤー2 + X | 150ms | 橙が1回点滅 | キー入力を優先したい場合 |
| レイヤー2 + C（デフォルト） | 800ms | 橙が3回点滅 | マウス操作を優先したい場合 |
| レイヤー2 + V → ↑ / ↓ | 100〜2000ms（10ms 刻み） | 橙で速く明滅し、↑ で長めに 1 回 / ↓ で短く 2 回光る | 好みの時間に合わせたい場合 |

中間の 400ms は、Vial の独自キー「AL 400」を割り当てて選ぶこともできます。

### オートレイヤーの無効化

レイヤー2 + Z キーで、オートレイヤー機能自体の ON/OFF を切り替えられます。

- **ON** → 緑が2回点滅
- **OFF** → 赤が2回点滅

OFF にしても、トラックポイントのカーソル移動・マウスボタン・**Scrl キーでのスクロール**は通常どおり使えます（スクロールはマウスレイヤーに依存しません）。マウスレイヤーを手動で使いたい場合は、レイヤー2の **「.」キー（TG(4)）**で ON/OFF できます。

---

## 音声フィードバック機能

OLSK60 はキー入力時に電子音を鳴らす音声フィードバック機能を搭載しています。デフォルトではOFFになっています。

### 全音声の ON/OFF

レイヤー2 + A キーで音声機能をまとめて ON/OFF できます。

- **ON** → 緑が2回点滅
- **OFF** → 赤が2回点滅

### サウンドモード

レイヤー2 + S キーで2つのモードを切り替えられます（音声がONの場合のみ有効。OFFの場合はLEDが赤く速く3回点滅し、操作が拒否されます）。

| モード | LED色 | 説明 |
|---|---|---|
| ランダムモード | 橙 | キーを押すたびにランダムな電子音が鳴ります |
| ピアノモード | 青 | キーの位置に応じた音階で発音します |

### ピアノモード

ピアノモードでは、キーボードの中段を中心にピアノの鍵盤のように音階が割り当てられます。

ピアノモードの音階配置図。ホームロー10キーが白鍵、上段7キーが黒鍵に相当し、Enterはタイプライター効果音

**白鍵に相当するキー（左から）：**
A → C（ド）、S → D（レ）、D → E（ミ）、F → F（ファ）、G → G（ソ）、H → A（ラ）、J → B（シ）、K → C（ド・1オクターブ上）、L → D（レ・1オクターブ上）、; → E（ミ・1オクターブ上）

**黒鍵に相当するキー：**
W → C#、E → D#、T → F#、Y → G#、U → A#、O → C#（1オクターブ上）、P → D#（1オクターブ上）

### ピアノオクターブの調整

ロータリーエンコーダ搭載モデルでは、レイヤー2でエンコーダを回すとピアノの音域を上下にシフトできます（-3～+3オクターブ。上げる = 青が1回 / 下げる = 青が2回点滅）。ピアノモード以外では赤く速く3回点滅し、操作は受け付けられません。

### Enterキーのタイプライター音

音声がONの状態でEnterキーを押すと、タイプライター風の効果音が鳴ります。

---

## ロータリーエンコーダ

ロータリーエンコーダ搭載モデルでは、各レイヤーでエンコーダに異なる機能が割り当てられています。

| レイヤー | 時計回り | 反時計回り | 押し込み |
|---|---|---|---|
| レイヤー0 | 音量ダウン | 音量アップ | ↓ |
| レイヤー1 | Page Down | Page Up | ↓ |
| レイヤー2 | ピアノオクターブ上げ | ピアノオクターブ下げ | ↓ |
| レイヤー3 | 音量ダウン | 音量アップ | ↓ |
| レイヤー4 | 音量ダウン | 音量アップ | ↓ |

> **補足:** レイヤー0の回転方向と音量の対応は、エンコーダの取り付け向きに依存します。直感と異なる場合は、設定ツール（Vial）でキーを入れ替えて調整できます。レイヤー3とレイヤー4はレイヤー0と同じ割り当て（透過）です。

---

## LEDインジケーター

OLSK60 には1個のLEDインジケーターがあり、現在のレイヤーやトラックポイントの設定状態を色で表示します。

**色の約束:** 緑 = オン・完了、赤 = オフ・受け付けない、黄 = 上限・下限、白 = 通常の状態。この4色はその意味にだけ使い、ほかの色はレイヤーや選んでいる項目を表します。**光り方**でも区別します: 点灯 = レイヤー、ゆっくり明滅 = オートレイヤー中、速い明滅 = 設定レイヤーで値を調整中、短い点滅 = 設定を変えた合図。

### レイヤー表示

| 状態 | LED色 |
|---|---|
| レイヤー0（通常時） | 白（暗め） |
| レイヤー1（Fn使用時 = Scrl キー押下中） | 青 |
| レイヤー2（設定キー押下中） | 橙 |
| レイヤー2で値を調整中（Q / W / E / V や矢印キーを押した後） | 選んだ対象の色で**速く**明滅（基本速度 = 青 / 加速度 = シアン / 減速度 = 紫 / 解除時間 = 橙） |
| レイヤー3（予備レイヤー） | シアン |
| レイヤー4（トラックポイント操作で自動 ON） | 速度プロファイルの色で**ゆっくり**明滅 |
| レイヤー4（「.」キーで手動 ON） | マゼンタ（赤紫）で点灯 |

### トラックポイント速度プロファイルの色

レイヤー4がトラックポイント操作で自動的に有効になっている間、選択中の速度プロファイルに応じた色でゆっくり明滅します。

| プロファイル | LED色 |
|---|---|
| 速度1（遅い） | 青 |
| 速度2（中間） | 紫 |
| 速度3（速い・デフォルト） | シアン |
| 速度4（調整枠） | マゼンタ（赤紫） |
| 速度5（調整枠） | 橙 |

### 設定操作時のLEDフィードバック

| 操作 | LED表示 |
|---|---|
| 速度プロファイル変更（1〜4） | プロファイルの色が2回点滅 |
| 値を上げる（↑） | 対象の色で長めに1回光る |
| 値を下げる（↓） | 対象の色で短く2回光る |
| 上限・下限に達した | 黄が速く3回点滅 |
| 操作を受け付けない（速度1・速度3 のときの調整、音声 OFF 中のモード切替など） | 赤が速く3回点滅 |
| 音声 ON / OFF（A） | 緑 / 赤が2回点滅 |
| サウンドモード：ピアノ / ランダム（S） | 青 / 橙が2回点滅 |
| ピアノオクターブ上げ / 下げ（エンコーダ） | 青が1回 / 2回点滅 |
| オートレイヤー ON / OFF（Z） | 緑 / 赤が2回点滅 |
| オートレイヤー解除時間 150ms / 800ms（X / C） | 橙が1回 / 3回点滅 |
| スクロールの効き方 ON / OFF（T） | 緑 / 赤が2回点滅 |
| 押し込みクリック ON / OFF（G） | 緑 / 赤が2回点滅 |
| 出荷時の設定に戻した（5 を 2 秒） | 緑がゆっくり3回点滅 |

> 最下段の Scrl キー自体は LED を光らせません（押している間スクロールになるだけです）。Q / W / E / V と ← / → も点滅はせず、明滅の色が切り替わるだけです。

---

## キーマップのカスタマイズ

キーマップは **Vial** で編集できます。**Remap / VIA には対応していません。**

### 対応する設定ツール

| ツール | 概要 | リンク |
|---|---|---|
| **Vial** | VIA系から派生したオープンソースの編集ツール。キーボード定義をファームウェアに内蔵するため、定義ファイルの読み込みは不要です。 | <https://get.vial.today/> |
| **Pipette** | Vial互換キーボード向けの設定アプリ（Windows / macOS / Linux）。Vial 公式アプリでロータリーエンコーダ周りの表示に不具合が出る場合はこちらをお試しください。 | <https://github.com/darakuneko/pipette-desktop> |

> **トラックポイント速度・オートレイヤー・スクロールなどの専用キー**は、Vial のキーコード一覧に独自キーとして並んでいます。好きな位置に割り当て直せます。

### Vial のアンロック操作

Vial / Pipette で一部の設定（マトリクステスター等）を使う際、キーボードのアンロックを求められることがあります。画面の指示に従い、**Esc キーと Enter キーを同時に長押し**してください。

Vial のアンロック操作。Esc と Enter を同時に長押しする

### Vial での基本的な使い方

1. [Vial](https://get.vial.today/) を起動し、キーボードを USB で接続します。
2. キーマップが表示されたら、変更したいキーをクリックして、下の一覧から新しいキーを選びます。
3. 変更はその場でキーボードに保存されます（書き込み操作は不要です）。
4. 元に戻したいときは、レイヤー2の 9（設定の全消去）で出荷時のキーマップに戻せます（設定も初期化されます）。

> **ファームウェアを書き込み直すと、Vial で変更した内容は初期化されます。**v3.0.0-rc.4 以降どうしの書き込みなら、書き込む前に `Save Current Layout` で保存し、書き込み後に `Load Saved Layout` で読み込み直せます。
>
> ⚠️ **旧版（v2.x）と、v3.0.0-rc.3 以前のテスト版で保存した `.vil` は読み込まないでください。** 独自キーの並びが変わっているため、別の機能が割り当てられます（Vial は保存元のキーボードを確認しません）。これらから移行する場合は組み直してください。

### カスタマイズ可能な項目

- 各レイヤーのキーマップ変更
- 独自キー（トラックポイント速度設定、音声設定、スクロール等）の配置変更
- 予備レイヤー（レイヤー3）へのキーの割り当て
- マクロの設定

> スペース列（5-Split / 3-Split）ごとの**出荷時キーマップ（プリセット）**は書き込むファイルで決まります。設定ツール側のレイアウト選択は画面表示だけで、打鍵の割り当ては変わりません（割り当ては Vial のキーマップ編集で変更します）。

### マトリクステスター

Vial にはマトリクステスター機能があり、すべてのキーが正しく動作するかを確認できます。キースイッチ取り付け後の動作確認にご活用ください。

---

## 特殊操作

### 出荷時の設定に戻す（キー配置はそのまま）

レイヤー2の **5 を押し続けて 2 秒**経つと、緑がゆっくり3回点滅し、次の設定が出荷時の状態に戻ります。キー配置（Vial で変更した内容）は変わりません。2 秒経つ前に離すと取り消されます。

- トラックポイントの速度プロファイル（速度3）と調整枠（速度4・速度5）の値
- オートレイヤーの ON/OFF と解除時間
- スクロールの効き方（T キーの設定）
- 押し込みクリック（G キーの設定）
- 音声機能の設定

### 設定の全消去（工場出荷状態へ戻す）

レイヤー2の **9** を押すと、保存されている設定とキー配置がすべて消去され、工場出荷状態に戻ります。

**リセットされる項目：**
- 上の「出荷時の設定に戻す」の項目すべて
- 設定ツールで変更したキーマップ

### キーボードの再起動

レイヤー2の右上端キー（Backspace位置）を押すと、キーボードが再起動します。設定は保持されます。

### ブートローダーモード（ファームウェア書き込み用）

ESCキーを押しながらUSBケーブルを接続すると、ブートローダーモードで起動します。ファームウェアの更新時に使用します。**ファームウェアが起動しない状態でもこの方法で書き込みモードに入れます。** キーボードが正常に動いているときは、レイヤー2の **0** のキー（BOOTSEL）でも同じモードに入れます。詳しくは [firmware/README.md](../firmware/README.md) をご参照ください。

---

## トラブルシューティング

| 症状 | 対処方法 |
|---|---|
| キーボードが認識されない | 1. USBケーブルを抜き差し → 2. 別のUSBポートを試す → 3. 別のケーブルを試す |
| 特定のキーが反応しない | 1. Vial のマトリクステスターで確認 → 2. キースイッチを挿し直す → 3. スイッチのピンが曲がっていないか確認 |
| トラックポイントが動かない | 1. ケーブルを抜き差しして再起動 → 2. フラットケーブルの接続を確認（[ビルドガイド](buildguide.md)参照） |
| LEDが点灯しない | 1. USBケーブルを抜き差し → 2. ファームウェアの再書き込みを試す |
| カスタム設定がリセットされてしまう | 設定の全消去（レイヤー2 + 9）や出荷時に戻す（レイヤー2 + 5 の長押し）を誤って押していないか確認。なお**ファームウェアを書き込み直すと設定は初期化されます** |
| トラックポイントの速度が合わない・反応が弱い | レイヤー2で速度プロファイルを変更。それでも遅い場合は速度5を選び、基本速度を上げてください。詳細は[マウス機能操作マニュアル](OLSK60_mouse_manual.md)参照 |
| 音が鳴らない | レイヤー2 + A で音声機能がONか確認（緑2回点滅 = ON） |
| スクロールが効かない | 最下段の **Scrl キー**（左親指）を押しながらトラックポイントを操作しているか確認。スクロールはマウスレイヤーの有無に関係なく使えます |
| キーマップがおかしい | Vial に接続してキーマップを確認。必要に応じてレイヤー2 + 9 で設定の全消去（工場出荷状態へ） |
| 押し込んでいないのにクリックされる | レイヤー2 + G で押し込みクリックを OFF にできます（赤2回点滅 = OFF） |
| 設定キーを押すと LED がシアンになる | 設定キーを短く押してから押し続けると、予備のレイヤー3に入ります。一度離して、押し続け直してください |
| Space が入力できない | **プリセットとトッププレートが合っていない**可能性があります。合うプリセット（3 分割なら `3split`）を書き込み直すか、Vial で押せる位置に Space を割り当て直してください（[スペースバーのレイアウトオプション](#スペースバーのレイアウトオプション)参照） |

そのほかのよくある質問は [FAQ](faq.md) にまとめています。

---

## 注意事項

- キーボードの清掃は定期的に行ってください。
- 強い衝撃を与えないように注意してください。
- 水気のある場所での使用は避けてください。
- トラックポイントの操作は軽い力で行ってください。無理な力を加えると破損の原因になります。

---

## サポート

ご不明点があれば [BOOTHの商品ページ](https://techmech.booth.pm/items/5896343) または [GitHub Issue](https://github.com/techmech-keeb/OLSK60_v2/issues) にてご連絡ください。

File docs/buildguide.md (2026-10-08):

# OLSK60 v2 ビルドガイド

このドキュメントは、OLSK60 v2（格子配列60%キーボード）の組み立て手順をまとめたものです。  
キットの内容物や別途必要なパーツについては、[BOOTHの商品ページ](https://techmech.booth.pm/items/5896343)または[遊舎工房の商品ページ](https://shop.yushakobo.jp/products/11324)をご確認ください。

> **初心者の方へ:** セクション1「カスタマイズのための準備」はスタビライザー交換や別売フォームの追加など、カスタマイズ目的の作業です。  
> まずは組み立てたい場合は、[セクション2「キースイッチの取り付け」](#2-キースイッチの取り付け)から始めてください。

> **モデルについて:** 現在販売中のモデルは **v2.1** で、出荷時は **5-Split Space** レイアウトです。同梱のトッププレートで 3-Split Space／6.25U Space にも変更できます。旧モデル **v2** は 3-Split Space および 6.25U Space のみに対応しています。

---

## 1. カスタマイズのための準備（任意）

スイッチプレートの交換、別売フォームの追加、スタビライザー交換などのカスタマイズを行う場合に、このセクションの手順を実施してください。カスタマイズが不要な場合はスキップできます。

### 1.1 基本セットの分解手順

スイッチプレートの交換や別売フォームの追加、スタビライザー交換を行う場合は、以下の手順で基本セットを分解してください。全体の構成は次の図のとおりです（分解は組み立ての逆順です）。

組み立ての構成順を示す分解図。上からキーキャップ、キースイッチ、トッププレート、スイッチフォーム（別売）、メイン基板、ケースの順。トラックポイントユニットはトッププレートの上でキースイッチの間に設置され、FFCはトッププレートとPCBの穴を通ってPCB裏面のコネクターへ接続する

1. 基板とスイッチプレートを分解する前に、トラックポイントとメイン基板を接続するフラットケーブル（FFC）を、**PCB裏面のコネクター**から外します。FFCはトッププレートとPCBの穴を通って裏面に回り込んでいます。

   フラットケーブルの取り扱い注意図。端子部を持ちまっすぐゆっくり抜き差しする。斜めに引っ張る・ねじる・強い力を加える・鋭角に折り曲げるのは禁止

   > ⚠️ **注意:** フラットケーブルのコネクターは非常にもろいため、無理な力を加えず慎重に取り扱ってください。

2. 基板とスイッチプレートがネジで固定されている場合は、付属のドライバーで全てのネジを外します。
3. スイッチプレートと基板をゆっくりと分離します。トラックポイントユニットやケーブルが引っかからないよう注意してください。
4. 必要に応じて、スタビライザーやフォームを取り外します。
5. 必要なパーツの交換・貼り付け・取り付け作業を行ってください。
6. 作業が完了したら、基板とスイッチプレートを元通りに重ね、ネジでしっかりと固定します。

> ⚠️ **注意:** 組み立て済みのトラックポイントユニットを無理に外そうとすると破損の原因となります。交換や調整が必要な場合は十分ご注意ください。

### 1.2 トッププレート（スイッチプレート）の交換（レイアウト変更）

OLSK60 v2.1 は、出荷時に **5-Split Space（1U・1U・1.25U・1U・1.75U）** レイアウトのトッププレートが取り付けられています。最下段のスペースバー構成を変更したい場合は、同梱の **3-Split Space／6.25U Space 兼用トッププレート** に付け替えてください。

> **補足:** 旧モデル v2 は 3-Split Space（2.25U・1.25U・2.75U）および 6.25U Space のみに対応しており、5-Split Space 用トッププレートは使用できません。

<!-- 任意写真: images/build/03-top-plates.jpg（2枚のトッププレートの切り欠き比較。実物依存のため図解では代替しない） -->

1. [セクション1.1](#11-基本セットの分解手順)の手順で基本セットを分解します。
2. トッププレートを使用したいレイアウトのものに交換します。
3. レイアウトに合わせてスタビライザーの位置を調整します（[セクション1.3](#13-スタビライザーの交換)参照）。
4. 交換後は、**そのスペース列に合う出荷時キーマップ（プリセット）を書き込む**と、Space などの割り当てがそのまま使えます（`5split` / `3split`）。ファームウェアの機能はどちらも同じで、キー配置は Vial でいつでも変更できます。詳しくは[操作ガイドのレイアウトオプション](OLSK60_user_guide.md#スペースバーのレイアウトオプション)をご参照ください。

### 1.3 スタビライザーの交換

スタビライザーは、選択するスペースバーレイアウトに応じて取り付け位置が変わります。

**出荷時（v2.1・5-Split Space）に取り付け済みの位置:**
- バックスペースキー（2U）
- エンターキー（2U）

5-Split Space レイアウトでは、最下段の各キーが小さいためスペースバー用のスタビライザーは使用しません。同梱の予備スタビライザー（2U×2）は、他のレイアウトへ変更する際にご使用ください。

**他のレイアウトに変更する場合:**
- 3-Split Space … 2.25U と 2.75U の位置に 2U スタビライザーを追加（同梱の予備を使用）
- 6.25U Space … 6.25U 用スタビライザーが別途必要です（キットには含まれません）。**v3 には 6.25U 用のプリセットがありません**ので、いずれかを書き込んだうえで Vial で割り当ててください

スタビライザーの取り付け位置図。5-Split はバックスペースとエンターの2箇所、3-Split では最下段に2箇所追加

> **補足:** 旧モデル v2 は、出荷時にバックスペース・エンターに加えて 2.25U・2.75U スペースバー用のスタビライザーも取り付けられています。6.25U Space に変更する場合は 6.25U 用スタビライザーを別途ご用意ください。

1. 必要な位置にスタビライザーを交換・取り付けます。
2. しっかりと固定されていることを確認してください。

### 1.4 スイッチフォームの設置（任意）

> ⚠️ **スイッチフォームはキットに含まれません。** 打鍵音や打鍵感を調整したい場合に、ユーザーご自身でご用意ください。取り付けは必須ではなく、フォームなしでも問題なく動作します。

1. **厚さ 3.5mm** のフォームをご用意ください。トッププレート下面とPCB上面の間隔が 3.5mm のため、この厚みがちょうど収まります（[2.1 スイッチの寸法](#21-スイッチの寸法)参照）。
2. 穴位置を合わせてPCB上に配置します（重ねる順序は[セクション1.1の分解図](#11-基本セットの分解手順)参照）。スイッチのピン・スタビライザー・トラックポイントユニットの取り付け部と干渉しないか確認してください。
3. FFCがトッププレートとPCBの穴を通るため、その経路をふさがないよう、必要に応じてフォームを切り欠いてください。

### 1.5 トラックポイントユニットの固定（必要に応じて）

トラックポイントユニットは**トッププレートの上、キースイッチとキースイッチの間**に設置されています（キット付属・組立済みです）。

1. ユニットがしっかりと固定されているか確認します。
2. ユニットが緩んでいる場合は、付属のネジやナットでしっかりと固定してください。
3. 必要に応じて動作確認を行ってください。

### 1.6 メイン基板とスイッチプレートの組み立て

1. スタビライザー（フォームを使う場合はフォームも）とトラックポイントユニットの取り付けが完了したら、メイン基板とスイッチプレートを重ねます。
2. 付属のネジでしっかりと固定します。
3. トラックポイントのFFCを、トッププレートとPCBの穴に通し、**PCB裏面のコネクター**へ再度接続します。奥まで確実に入っているか確認してください（取り扱いの注意点は[セクション1.1の図](#11-基本セットの分解手順)参照）。

   > ⚠️ **注意:** コネクターは非常にもろいため、無理な力を加えず慎重に取り扱ってください。

---

## 2. キースイッチの取り付け

1. 取り付ける前に、各キースイッチのピンが曲がっていないかよく確認してください。

   取り付け前のピン確認図。ピンがまっすぐなら良い。曲がっている場合はまっすぐに直してから取り付ける

2. スイッチをスイッチプレートとPCBにまっすぐゆっくりと差し込みます。位置を確かめながら、無理な力を加えずに差し込んでください。

   キースイッチの差し込み方の断面図。真上からまっすぐ差し込み、下から指でソケットを軽く支える

   > **ヒント:** 差し込み時は下側からソケットを軽く抑えながら作業すると、ソケットの破損防止になります。

3. すべてのキースイッチを差し込んだら、[Vial](https://get.vial.today/) に接続し、マトリクステスターで全てのキーが正しく動作するか一つずつ確認してください。

### 2.1 スイッチの寸法

OLSK60 は **MX互換**のキースイッチに対応しています。スイッチを別途購入する場合や、プレート・キーキャップとの寸法関係を確認したい場合は次の図を参照してください。

MX互換キースイッチの三面図。正面図・側面図・上面図・底面のピン配置・プレートマウント断面を、寸法（mm）付きで示す

主要な寸法は次のとおりです（単位 mm）。

| 項目 | 寸法 |
|---|---|
| 全高（ステム頂点〜ピン先端） | 18.5 |
| トップハウジング外形 | 15.6 × 15.6 |
| プレート開口（下部ハウジングが通る部分） | 14.0 × 14.0 |
| プレート厚 | 1.5 |
| キースイッチピッチ（1U） | 19.05 |

> 各部の内訳・PCB フットプリントの座標・ステムの参考値は、[MX互換スイッチ 寸法リファレンス](reference/cherry-mx-switch-spec.md)にまとめています。

OLSK60 側の積層寸法は次のとおりです（[差し込み方の断面図](#2-キースイッチの取り付け)と対応）。

| 部位 | 寸法 |
|---|---|
| トッププレート厚 | 1.5 |
| トッププレート下面〜PCB上面 | 3.5 |
| PCB厚 | 1.6 |
| ホットスワップソケット厚（PCB裏面） | 2.0 |

スイッチのハウジングはプレート上面から 4.8mm 下まで、ピン先端は 8.1mm 下まで伸びるため、ピンは PCB を貫通して裏面のソケットに届きます。

> トッププレート下面とPCB上面の 3.5mm の空間は、**別売のスイッチフォーム（3.5mm厚）**がちょうど収まる厚みです。フォームはキットに含まれないため、使用する場合はご自身でご用意ください（[1.4 スイッチフォームの設置（任意）](#14-スイッチフォームの設置任意)参照）。

---

## 3. キーキャップの取り付け

1. 各キースイッチにキーキャップを取り付けます。
2. 配列・サイズに注意してください。出荷時の 5-Split Space レイアウトでは、最下段に 1U キー 3 個と 1.75U キー 1 個を使用します。

### 3.1 キーキャップサイズガイド

各キーに必要なキーキャップのサイズ（1U＝標準1キー分の幅）を、スペースバーのレイアウトオプションごとに図示します。**上4段は全レイアウト共通で、最下段だけが異なります。** 各図の下部に、その構成でキーボード全体に必要なサイズ別の個数をまとめています。

> **補足:** 対応するスペースバーレイアウトはモデルによって異なります（v2.1 は 5-Split がデフォルト、v2 は 3-Split がデフォルト）。詳しくは[「1.2 トッププレートの交換」](#12-トッププレートスイッチプレートの交換レイアウト変更)および[操作ガイドのレイアウトオプション](OLSK60_user_guide.md#スペースバーのレイアウトオプション)をご参照ください。

**5-Split Space（v2.1 出荷時）**

5-Split Space レイアウトの全キーキャップサイズ図。各キーに刻印名と幅（U）を表示し、サイズ別に色分け。下部にサイズ別の必要数を掲載

**3-Split Space（v2 出荷時 / v2.1 でも選択可）**

3-Split Space レイアウトの全キーキャップサイズ図。各キーに刻印名と幅（U）を表示し、サイズ別に色分け。下部にサイズ別の必要数を掲載

**6.25U Space（v2 / v2.1）**

6.25U Space レイアウトの全キーキャップサイズ図。各キーに刻印名と幅（U）を表示し、サイズ別に色分け。下部にサイズ別の必要数を掲載

> **スタビライザーについて:** 2U 以上のキー（Backspace・Enter や、3-Split の 2.25U・2.75U、6.25U スペースバー）にはスタビライザーが必要です。取り付け位置は[「1.3 スタビライザーの交換」](#13-スタビライザーの交換)を参照してください。

---

## 4. ケースへの組み込み

1. 組み立てたPCB＋プレート＋スイッチをGH60互換ケースに組み込みます。
2. ケース付属のネジで固定します。

---

## 5. ファームウェアの確認

OLSK60 v2は出荷時にファームウェアが書き込まれています。出荷時のファームウェアは 5-Split Space レイアウトに対応しています。**v3.0.0 の公開（2026年10月8日）より前に購入された場合は旧版（v2.x）が書き込まれているので、[firmware/README.md](../firmware/README.md) の手順で v3 に更新してください。**

> **補足:** v3 は Vial 専用です。どちらが書き込まれているかわからない場合も、更新して問題ありません（キーボードに保存された設定は初期化されます）。旧版の説明は [v2.0.3 時点の説明](https://github.com/techmech-keeb/OLSK60_v2/tree/v2.0.3) に残しています。

ファームウェアの更新が必要な場合は、[firmware/README.md](../firmware/README.md)をご参照ください。

1. USBケーブルでPCと接続します。
2. すべてのキー・トラックポイントが正常に動作するか確認してください。
3. v3 のキーマップのカスタマイズには [Vial](https://get.vial.today/) を使用します。キーボード定義はファームウェアに内蔵されているので、定義ファイルの読み込みは不要です。
4. v3 を書き込む場合は、**お使いのスペース列に合うプリセット**（`5split` / `3split`）を選ぶと、そのまま調整なしで使えます（機能はどちらも同じです）。詳しくは [firmware/README.md](../firmware/README.md) をご参照ください。

---

## 6. トラブルシューティング

| 症状 | 対処方法 |
|---|---|
| キーが反応しない | スイッチを抜き差しし、ピンが曲がっていないか確認してください。改善しない場合はソケットの状態を確認してください |
| 複数キーが反応しない | フラットケーブルの接続を確認してください（[セクション1.1](#11-基本セットの分解手順)参照） |
| トラックポイントが動作しない | フラットケーブルの接続を確認してください。ケーブルを抜き差しして再起動もお試しください |
| キーボードがPCに認識されない | USBケーブルを抜き差し → 別のUSBポートを試す → 別のケーブルを試す |
| スタビライザーが引っかかる | スタビライザーが正しい位置にはまっているか、ワイヤーが外れていないか確認してください |

---

## 7. 次のステップ

組み立てが完了したら、以下のドキュメントで使い方をご確認ください。

- [キーボード操作ガイド](OLSK60_user_guide.md) — レイヤー構成や各機能の使い方
- [マウス機能操作マニュアル](OLSK60_mouse_manual.md) — トラックポイントの速度調整

---

## 8. サポート

ご不明点があれば[BOOTHの商品ページ](https://techmech.booth.pm/items/5896343)または[GitHub Issue](https://github.com/techmech-keeb/OLSK60_v2/issues)にてご連絡ください。

---

以上で組み立ては完了です。お疲れ様でした！

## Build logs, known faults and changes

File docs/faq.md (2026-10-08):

# OLSK60 よくある質問（FAQ）

OLSK60 v2 シリーズについて、お問い合わせの多い項目をまとめています。  
記載のない症状は[操作ガイドのトラブルシューティング](OLSK60_user_guide.md#トラブルシューティング)もご確認ください。

> **本書が前提とするファームウェア:** **v3.0.0 以降**（Vial 対応・本リポジトリの[最新リリース](https://github.com/techmech-keeb/OLSK60_v2/releases/latest)）です。旧版（v2.x）をお使いの方は、[v2.0.3 時点の説明](https://github.com/techmech-keeb/OLSK60_v2/tree/v2.0.3)をご覧ください。

---

## モデル・ファームウェアの選択

### Q. 自分の個体が v2 か v2.1 か分かりません

基板上のシルク印刷（バージョン表記）をご確認ください。また、最下段が5つの小さいキーに分かれたトッププレート（5-Split Space）が付いている個体は v2.1 です。v2 の基板は 5-Split Space に対応していません。

### Q. v3.0.0 より前に購入しました。ファームウェアを更新する必要はありますか？

**はい、更新してください。** v3.0.0 の公開（2026年10月8日）より前に購入された個体には、旧版（v2.x）が書き込まれています。本リポジトリの説明は v3 を前提にしています。どちらが書き込まれているかわからない場合も、更新して問題ありません（キーボードに保存された設定は初期化されます）。v3 での主な変更点と手順は [firmware/README.md](../firmware/README.md) をご参照ください。

### Q. どのファイルを書き込めばよいですか？

**機能はどちらも同じ**で、違うのは**出荷時のキーマップ（プリセット）**だけです。お使いのトッププレートのスペース列に合うものを選ぶと、書き込んだあと**調整なしでそのまま使えます**。

| スペース列 | そのまま使えるプリセット |
|---|---|
| 5 分割（v2.1 の出荷時） | `..._Vial_5split.uf2` |
| 3 分割 | `..._Vial_3split.uf2` |
| 6.25U | 専用プリセットはありません（いずれかを書き込み、Vial で割り当ててください） |

**どちらを書き込んでも動作します。**合わないプリセットのままだと Space などが押せない位置に載るので、その場合は Vial で割り当て直してください。

書き込んだ直後の Vial の Layout タブは **3-Split** 表示です。5-Split のキーボードでは「5-Split Space」を選び直してください（表示だけの設定です）。

### Q. Remap や VIA は使えますか？

v3 は **Vial 専用**です。Remap / VIA には対応していません。

---

## 設定ツール

### Q. Vial でキーボードが認識されません

USB ケーブルがデータ通信に対応しているか、別のポートで試せるかをご確認ください。v3 は定義をファームウェアに内蔵しているので、定義ファイルの読み込みは不要です。

### Q. Vial 公式アプリでロータリーエンコーダが表示されません

Vial 公式アプリの既知の不具合です。Vial 互換の設定アプリ [Pipette](https://github.com/darakuneko/pipette-desktop) では正しく表示されるため、Pipette のご利用を推奨します。

### Q. Vial / Pipette で「アンロックしてください」と表示されます

マトリクステスターなど一部機能の利用時に、誤操作防止のためアンロックが求められます。画面の指示に従い、**Esc キーと Enter キーを同時に長押し**してください。

Vial のアンロック操作。Esc と Enter を同時に長押しする

---

## キーマップ・レイアウト

### Q. Space が入力できません

**書き込んだプリセットとトッププレートが合っていない**可能性が高いです。Space が物理キーの無い位置に載っている状態で、故障ではありません。次のどちらかで直ります。

1. お使いのスペース列に合うプリセット（3 分割なら `3split`）を書き込み直す。
2. Vial で、押せる位置のキーに Space を割り当て直す。

詳しくは[操作ガイドのレイアウトオプション](OLSK60_user_guide.md#スペースバーのレイアウトオプション)をご参照ください。

### Q. 左親指のキーが Fn ではなく「Scrl」になっています

v3 では、従来 Fn（MO(1)）だった左親指のキーが **Scrl キー**になりました。押している間は **Fn レイヤーがそのまま使えます**。加えて、押しながらトラックポイントを動かすとスクロールになります。

### Q. 旧版で保存したキーマップ（`.vil`）を読み込んでも大丈夫ですか？

**旧版（v2.x）と、v3.0.0-rc.3 以前のテスト版で保存したファイルは読み込まないでください。** 独自キー（トラックポイントの速度・サウンド・オートレイヤーなど）の並びが変わっており、読み込むと**別の機能が割り当てられます**。Vial は保存元のキーボードを確認しないため、そのまま書き込まれてしまいます。お手数ですが Vial で組み直してください。

v3.0.0-rc.4 以降どうし（例: 今後の版への更新）であれば、`Save Current Layout` → `Load Saved Layout` で問題なく戻せます。

### Q. キーマップを出荷時の状態に戻したい

レイヤー2（最下段の設定キーを押しながら）で **9** を押すと、設定の全消去を実行します。キーマップを含むすべての設定が工場出荷状態に戻ります。**ファームウェアを書き込み直したときも初期化されます。**

キーマップはそのままで、トラックポイントやオートレイヤーなどの設定だけを戻したい場合は、レイヤー2で **5 を 2 秒押し続けて**ください（緑がゆっくり3回点滅）。

### Q. 設定レイヤーに入るキーはどれですか？

最下段の **Delete の右のキー（設定キー）**です。押している間は設定レイヤー（LED 橙）になります。**短くタップしてから押し続ける**と、自由に使える予備のレイヤー3（LED シアン）に入ります。設定レイヤーに入ったつもりで LED がシアンになったときは、一度離してから押し続け直してください。

---

## トラックポイント

### Q. ファームウェアを書き込んだ直後、トラックポイントの押し下げクリックが効きません

旧版（v2.x）での既知の動作です。**v3 で同じ症状が出るかは未確認**ですが、押し下げクリック（Depress機能）が効かないときは、まずレイヤー2 + **G** で押し込みクリックが ON になっているか確認してください（緑2回点滅 = ON）。それでも効かない場合は **USB ケーブルを一度抜き、挿し直して再起動**してみてください。改善しない場合は [Issues](https://github.com/techmech-keeb/OLSK60_v2/issues) へご報告いただけると助かります。

### Q. カーソルの速度を変えたい

レイヤー2 + 数字キー 1〜4 で速度プロファイル（速度1 / 速度3 / 速度4 / 速度5）を切り替えられます。さらに細かく調整したい場合は[マウス機能操作マニュアル](OLSK60_mouse_manual.md)をご参照ください。

### Q. トラックポイントの反応が弱い・速度を最大にしても遅いです

レイヤー2で **4**（速度5）を選び、**Q** を押してから **↑** を押すたびに基本速度が上がります。上限に達すると黄色く3回点滅します。速度を上げるほど、ゆっくり動かしたときの最小の移動量も大きくなる点にご注意ください。改善しない場合は [Issues](https://github.com/techmech-keeb/OLSK60_v2/issues) へご報告いただけると助かります。

### Q. 押し込んでいないのにクリックされてしまいます

トラックポイントの押し込みクリック（Depress機能）は、レイヤー2 + **G** で OFF にできます（赤2回点滅 = OFF）。設定はキーボード内に保存されます。

### Q. スクロールの効きが強すぎます / 弱すぎます

v3 のスクロールは、**強く操作するほど速く進む**調整が出荷時から有効です。レイヤー2 + **T** で従来の動きに戻せます（緑2回点滅 = 有効、赤2回点滅 = 従来どおり）。

### Q. 同時に押せるキー数は？

**6 キーまで**です（標準的な USB キーボードと同じ）。

---

## 音・LED

### Q. 音が鳴りません / 音を消したい

打鍵音はデフォルトで OFF です。レイヤー2 + A キーで ON/OFF を切り替えられます（ON: 緑2回点滅、OFF: 赤2回点滅）。

### Q. LED の色は何を表していますか？

現在のレイヤーとトラックポイント設定の状態を表します。緑 = オン・完了、赤 = オフ・受け付けない、黄 = 上限・下限、白 = 通常の状態が共通の約束です。光り方でも区別します（点灯 = レイヤー、ゆっくり明滅 = オートレイヤー中、速い明滅 = 値を調整中）。[操作ガイドの LED インジケーター](OLSK60_user_guide.md#ledインジケーター)に一覧があります。

---

## ファームウェア書き込み

### Q. ブートローダーモードに入れません

1. キーボードを PC から外します。
2. **Esc キーを押しながら** USB ケーブルを接続します。
3. PC に「RPI-RP2」という名前のドライブが表示されれば成功です。

表示されない場合は、別の USB ポート・ケーブルをお試しください。詳しくは [firmware/README.md](../firmware/README.md) をご参照ください。

---

## サポート

解決しない場合は [BOOTHの商品ページ](https://techmech.booth.pm/items/5896343) または [GitHub Issue](https://github.com/techmech-keeb/OLSK60_v2/issues) にてご連絡ください。

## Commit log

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2025-05-08 OLSK60キーボード操作ガイドを更新し、作成中のステータスを追加。基本的なキー配列の説明を修正し、レイヤー切り替え方法を明確化。新しい画像ファイルを追加。
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2025-05-10 README.mdのファイル構成セクションで、`olsk60_via.uf2`ファイルへのリンクを追加し、手順4の説明をリンク付きに修正しました。
2025-05-10 ビルドガイドを更新し、キットに含まれるものと別途用意が必要なものを明確に分けました。また、対応ケースの名称を修正し、購入先の情報を整理しました。
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2025-11-23 README.mdを更新し、トラックポイントカバーのカスタマイズ用STEP/STLファイルへのリンクを追加しました。
    [OLSK60 TrackPoint Unit ND4.1.step, OLSK60 TrackPoint Unit ND4.1.stl]
2026-06-19 docs: READMEとビルドガイドを整理
    - READMEからパーツリスト・qmk_firmwareソースコードへのリンクを削除
    - READMEにマウス機能操作マニュアルへのリンクを追加
    - ビルドガイドから部品リストセクションを削除（BOOTH商品ページへ誘導）
    - ビルドガイドのセクション番号を振り直し
    - GitHub Issueリンクのorg名を修正
    Claude-Session: https://claude.ai/code/session_01WDuMBYLsjEXWs7Pr5pPVyK
2026-06-19 docs: ユーザーガイドとマウスマニュアルを全面改訂
    - OLSK60_user_guide.md: ソースコードに基づく正確な4レイヤー構成、速度プロファイル（3固定+2カスタムバンク）、オートレイヤー遅延プリセット、音声フィードバック、LEDリファレンスを網羅
    - OLSK60_mouse_manual.md: 速度プロファイル値・パラメータ範囲・カスタムバンク仕様を正確な値に修正、スムージングパラメータ（存在しない）を削除
    - README.md: 不要なリンク削除、マウスマニュアルリンク追加
    - buildguide.md: パーツリスト削除、GitHub Issueリンク修正
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2026-06-19 docs: 全ドキュメントの総合見直し — 初心者・熟練者の両方に対応
    - README.md: 初心者向け読み順ガイド追加、リンクに説明文を付与、firmware/直リンク化
    - buildguide.md: セクション構成を初心者に優しい順序に再編、ベアURLをMarkdownリンク化、
    トラブルシューティング充実、画像プレースホルダー追加、次のステップセクション追加
    - OLSK60_user_guide.md: クイックスタートセクション追加、未使用のmouse_setting.png埋め込み、
    最下段キーテーブルの全サイズ記載、スペースバー表記の矛盾修正、alt文改善、
    ロータリーエンコー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
2026-06-19 docs: サポートセクションから遊舎工房リンクを削除
    遊舎工房は委託販売のみで問い合わせ対応は行わないため、
    サポート・問い合わせ先はBOOTHとGitHub Issueのみに戻す。
    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
2026-06-21 docs: v2/v2.1のスペースバーレイアウトオプションを正しい仕様に修正
    レイアウトオプション名をVIA定義に合わせて修正し、5-Split-Spaceが
    v2.1のみ対応である旨の注意書きを追加。
    Claude-Session: https://claude.ai/code/session_01DDemfDixpLj5bifzVZc1Ja
2026-06-22 docs: ファームウェアREADMEをVIA/Vial対応に更新
    - VIA用/Vial用ファームウェアと配布ファイルの案内を追加
    - 旧版ファームウェア個体（〜2026年6月）はRemap利用を案内
    - 設定ツール（Remap/VIA/Vial/Pipette）の概要を追記
    - Vialのエンコーダ表示不具合とPipette推奨を明記
    - デフォルト5-Split Spaceレイアウトを反映
2026-06-22 docs: READMEをv2.1・VIA/Vial対応に更新
    - 現行モデルv2.1とデフォルト5-Split Spaceを概要に反映
    - Remap/VIA/Vial（Pipette）対応を特徴に追記
    - ファームウェア節に旧版/更新時の案内を追加
    - 購入表に販売形態と問い合わせ先（Techmech keys）を明記
2026-06-22 docs: ビルドガイドを5-Split出荷・VIA/Vialに更新
    - トッププレート交換（レイアウト変更）の手順を追加
    - スタビライザー構成を5-Split出荷基準に修正、v2/v2.1差を明記
    - ファームウェア確認をVIA/Vial・旧版Remapの案内に更新
2026-06-22 docs: 操作ガイドをデフォルト5-Split・VIA/Vial対応に更新
    - スペースバーのレイアウトオプションのデフォルトを5-Split(v2.1)に修正
    - レイアウト切替の対応ツールにVIA/Vialを追記
    - 設定ツール（VIA/Vial/Pipette）の概要を追加、Pipette推奨を明記
    - 旧版ファームウェア個体のRemap利用案内を追記
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2026-07-09 docs: FAQを新設し、READMEに仕様表と出荷時キー配列図を追加
    - FAQ: モデル判別・ツール選択・VIA定義読み込み・Vialアンロック・
    書き込み直後の押し下げクリック無効などお問い合わせの多い項目を集約
    - README: 仕様表・レイヤー0配列図・FAQへの導線を追加
    - firmware/README: 更新後の再起動が必要な理由（押し下げクリック）を明記
    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
2026-07-18 tools: キー配置図ジェネレータ keydiagram を追加
    既存の docs/images レイヤー図と同一様式のSVG/PNGを、表示レイアウト
    （layouts/olsk60.yaml）と図スペック（diagrams/*.yaml）から生成する。
    TrackPoint・エンコーダ等のレイアウト外情報は hardware: で別枠管理。
    verify_style.py が layer0-base.svg のバイト一致再現を回帰テストとして保証。
    Claude-Session: https://claude.ai/code/session_01KXeZwnrWZC9mufsK7vrEwo
2026-07-18 docs: ピアノモードの音階配置図を追加
    key_sound.c の keycode_to_semitone() に基づき、白鍵10キー・黒鍵7キー・
    Enter効果音・オクターブ調整を既存レイヤー図と同一様式で図解し、
    ユーザーガイドのピアノモード節から参照する。図は tools/keydiagram で生成。
    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
2026-07-24 tools: keydiagram に最下段バリアントとサイズ表示モードを追加
    - layouts に variants:（5-split/3-split/6.25u）を追加。上4段共通、最下段を
    replace_y で差し替え。座標の出典は olsk60_via.json のレイアウトオプション。
    - label_mode: size で全キーに刻印名＋幅（例 1.25U）を表示。size_palette で
    サイズ別に色分け。legend_mode: sizes でサイズ別の必要数を自動集計・凡例化。
    - キーキャップサイズガイドの図スペック3種を追加。
    - 既存レイヤー図の様式は不変（verify_style.py の layer0 バイト一致は維持）。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
2026-07-24 docs: キーキャップサイズガイドをビルドガイドに追加
    スペースバー3レイアウト（5-Split / 3-Split / 6.25U）ごとに、全キーの
    キーキャップサイズを各キーに表示した図とサイズ別必要数を掲載。上4段は
    全レイアウト共通で最下段のみ異なることを明記。操作ガイドのレイアウト
    オプション節と相互リンク。図は tools/keydiagram で生成。
    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
2026-07-24 docs: ビルドガイドのスイッチ図をMX系立面に刷新
    switch-pins / switch-mount / build-exploded の3図で、簡略な箱だった
    スイッチ描画を、データシート正面図に準拠したMX系スイッチ立面
    （ステム十字・段付きハウジング・くびれ・中央ボス）へ差し替え。
    共通グリフを各図で <use> 参照し、既存図の配色・線幅の様式は維持。
    各図の用途・ラベル・向き（ピン確認は裏面ピン、断面はステム上・ピン下、
    分解図はキーキャップ側にステム）と曲がりピンの赤描画は保持。
    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
2026-07-24 docs: スイッチ図をデータシート実寸比の正面図に修正
    前回のスイッチ描画が実物の比率とかけ離れていたため、データシートの
    正面図（左上・側面立面）の寸法に忠実な形状へ描き直した。
    実寸比 1mm=8px で作図:
    - 幅: 上部ハウジング 15.6mm、プレート貫通部 14mm（段差フランジで表現）
    - 縦: ステム3.6 + ハウジング11.6（上部5.0/下部6.6）+ 中央ポール3.3 = 総高18.5mm
    十字ステム・プレート載置フランジ・中央ポール・ピンを実物の位置関係で配置。
    switch-pins / switch-mount / build-exploded の共通グリフを更新。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
2026-07-24 docs: スイッチ図の正面形状をより忠実にトレース
    データシート正面図の輪郭を作り込み、実物のMXスイッチにより近づけた:
    - 上部ハウジングの傾斜した肩（トップに向かって細くなる形状）
    - プレートに載るフランジのリップ張り出し（上部15.6mm→下部14mmの段差）
    - 十字ステム・中央ポール・前面モールドライン
    実寸比（1mm=8px）は維持。共通グリフを switch-pins / switch-mount /
    build-exploded の3図で更新。
    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
2026-07-24 docs: スイッチ寸法資料を再配置し出典と日本語ラベルを整備
    アップロードされた寸法資料と5面図を用途別に配置する。
    - 寸法表: docs/reference/ へ移動（docs/直下はユーザー向けマニュアル用のため）。
    出典・最終確認日・図へのリンク・商標の注記を追記。
    - 5面図: docs/images/ へ移動（図の集約先に統一）。ラベルを日本語化し、
    他図と同じCJKフォントスタックに合わせてPNGを併置。
    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
2026-07-24 docs: スイッチ図を三面図由来の実形状に差し替え、共通部品化
    手描きだったスイッチ描画を、docs/images/cherry-mx-switch-views.svg の
    正面図から取り出した実形状（6px=1mm）に置き換えた。ピンの左右非対称も
    実物どおりになる。
    形状は tools/keydiagram/parts/mx-switch.svg をマスターとし、sync_parts.py で
    switch-pins / switch-mount / build-exploded の3図へ複製する。GitHub上のSVGは
    外部ファイル参照が効かないため各図にインライン複製する必要があり、--check で
    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
2026-07-24 docs(keydiagram): 出典表記から内部参照を除き一般化する (#11)
    図の座標・音階マッピングの出典メモが、開発側の非公開リポジトリ名・
    ディレクトリ構成・ソースファイル名・内部識別子を含んでいた。公開
    リポジトリの秘匿方針に反するため、出典としての意味を保ったまま
    一般的な表現へ置き換える。
    - 座標の出典は「製品の物理レイアウト定義」「VIA 用キーボード定義
    JSON」と表記する。
    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
2026-07-24 docs: 断面図・分解図の積層寸法を実物比に修正
    スイッチ（8px=1mm）を基準に、図中の他要素の寸法を実測値へ合わせた。
    - 断面図: プレート1.5mm / プレート下面〜PCB上面3.5mm / PCB1.6mm /
    ソケット2.0mm を実寸比で描画。3.5mm は寸法線、各層の厚みはラベルに併記。
    - 分解図: プレート・PCB・ソケットの厚みの相対関係を実物比に修正
    （従来はソケットがプレートより薄く見えていた）。
    - ビルドガイド 2.1 に積層寸法の表を追加。ハウジング4.8mm・ピン8.1mm と
    合わせ、ピンがPCBを貫通して裏面ソケットに届くことを明記。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
2026-07-24 docs: フォームを別売扱いに改め、TPユニット位置とFFC経路を修正
    実機の構造に合わせて分解図と本文を修正した。
    - スイッチフォーム: 3.5mm厚に修正し、キット非同梱・任意である旨を明示。
    1.4 を「（任意）」に改題し冒頭で非同梱を警告、前置き・組立手順の
    「フォーム貼り付け」表現も「別売フォームの追加」に統一。プレート下面〜
    PCB上面の3.5mmがフォーム厚とちょうど一致することを断面図と2.1に補記。
    - トラックポイントユニット: トッププレートの上・キースイッチの間へ移動
    （従来はフォームとPCB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
2026-09-16 docs: regenerate the layer diagrams for the candidate keymap
    The figures still show the keymap of the shipping firmware: the left thumb key
    as MO(1) although it is now the scroll key (scroll plus Fn while held), the Fn
    diagram missing the encoder press line, and the mouse diagram claiming the
    encoder does nothing there. Bring the three layer specs over, relabel the thumb
    key in the shared layout, and regenerate every figure that key appears in,
    including the 3-Split keycap guide, whose thumb row is Space / Scrl / Delete in
    the candidate build.
    Claude-Session: https://claude.ai/code/session_01EcW3vMj6dHMbdMvSbQogaq
2026-09-16 docs: redraw the bottom-row figure around which file to flash
    Under the candidate firmware the space row is no longer a config-tool option
    that leaves keys to reassign — it is decided by the file you flash, and the
    3-Split build lands Space, the scroll key and Delete on the plate directly. Say
    that instead of the reassignment warnings, and mark 6.25U as having no
    candidate build at all.
    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
2026-09-16 docs: rewrite the user guide for the candidate firmware
    Nearly every section named a tool or a key the candidate build no longer has:
    Remap and VIA as editors, the left thumb key as Fn, the space row as a config
    option to switch, and LED colours from the shipping firmware (Fn cyan, settings
    green, auto-layer toggle green/red). Go through it against the candidate
    keymap: Vial only, the thumb key as the scroll key that still gives Fn, the
    space row decided by the file you flash, the new T key for scroll feel, BOOTSEL
    on the settings layer, and the LED table redone from the firmware's own values.
    Claude-Session: https://claude.ai/code/sessi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
2026-09-16 docs: rewrite the mouse manual for the candidate firmware
    Scrolling moved: it is the left thumb key now, works whether or not the mouse
    layer is up, sends finer steps and speeds up the harder you push. The profile
    names are numbers on the LED, and the auto-layer toggle blinks cyan/orange, not
    green/red. Update those, add the T key that switches the scroll feel, and stop
    calling stored settings EEPROM.
    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
2026-09-16 docs: describe the two files as presets, not layout-specific firmware
    Saying the space row "is decided by the file you flash" and warning about
    mixing them up reads as though each plate needs its own firmware. It does not:
    the builds are the same firmware with two default keymaps, offered so each
    plate works untouched, and either one can be remapped in Vial at any time.
    Reword every place that framed it as a per-layout build, and say what actually
    happens with a mismatched preset and how to fix it without reflashing.
    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
2026-09-17 docs: describe trackpoint force as how hard you operate it, not pressing down
    "押し込み" and "強く押す" read as pushing the stick straight down, which is the
    press-to-select click, not the sideways force that sets the speed. Say "操作の
    強さ" instead everywhere the scroll curve is described. The encoder table keeps
    押し込み, where it really is a press.
    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
2026-10-07 docs: redraw the layer diagrams for the v3.0.0-rc.4 keymap
    The settings key is now a tap dance (label 設定, TD(0)), the mouse layer
    moved to layer 4 (TG(4)), and layer 2 was rearranged: target select on
    Q/W/E/V, adjust on the arrow keys, auto layer on Z/X/C, sound on A/S,
    Z-Tap on G, reset-to-defaults on 5, clear-all on 9.
    Claude-Session: https://claude.ai/code/session_015xpvG4XfCaiMV1hGZefJf9
2026-10-07 docs: update the firmware page for v3.0.0-rc.4
    Layout files saved on rc.3 or earlier must not be loaded, Vial now opens
    on the 3-Split view, and the change list covers the five layers, the tap
    dance settings key, the new settings layer, the LED colour rules, the
    reset key, the Z-Tap switch and the higher base-speed limit.
    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
2026-10-07 docs: rewrite the user guide's settings, layer and LED sections for rc.4
    Describe the new layer 2 (number keys 1-4, Q/W/E/V with arrows, Z/X/C,
    A/S, T, G, 5, 9, 0, .), the spare layer 3 and the mouse layer as layer 4,
    the green/red/yellow LED rules and new colours, and both reset paths.
    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
2026-10-07 docs: rewrite the mouse manual's adjust steps and LED tables for rc.4
    Adjusting now means picking a target with Q/W/E (or V for the auto-layer
    time) and stepping with the arrow keys; profiles 1-4 on the number keys;
    new colours and the yellow limit blink; higher base-speed limit with its
    trade-off; Z-Tap switch on G.
    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
2026-10-07 docs: switch the test-version wording to the official v3.0.0 release
    The firmware these docs describe becomes the official release, so the
    "テスト版" disclaimers become "v3", and readers who stay on v2.x are
    pointed at the v2.0.3 docs and release instead of "the latest release",
    which will now be v3.
    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
2026-10-08 docs: describe the v3.0.1 LED colours and patterns
    v3.0.1 reserves white for the normal state, distinguishes states by how
    the LED lights (steady, slow or fast breathing, short blinks), regroups
    the speed colours, makes the manual mouse layer magenta, and signals
    up/down by blink count. Update every LED table, the two diagrams, and
    note that TG switches the mouse layer on key release.
    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
2026-10-16 docs: redraw the build-guide assembly figures in 3D and fix the steps
    Replace the exploded view, FFC handling, stabilizer positions, pin check
    and switch insertion figures with labelled 3D renders, and add a figure
    for the corner mounts and the case fit. Describe how the board is held
    (spacers screwed from both sides, O-rings pressing on the case walls,
    no case screws), the 2.25U Enter, the 1.6 mm plate, the switch
    orientation, and the 5-Split bottom-row keycap sizes.
    Claude-Session: https://claude.ai/code/session_0131FaQTqTWWCuVEr83A3pz8
2026-10-16 docs: place the optional rotary encoder on the bottom row in the README
    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
2026-10-16 docs: match the guides and key diagrams to firmware v3.0.2
    - Encoder: clockwise turns volume / page / octave up on every layer.
    - 3-Split: mouse buttons are on the mouse layer only (quick start,
    button tables, auto mouse layer OFF).
    - Scrl key lights the LED blue (Fn layer); Fn diagram names the Scrl key.
    - Fn table: add Num Lock (N) and apostrophe (,).
    - Speed 1 to 3 all refuse adjustment; octave limits blink red.
    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
2026-10-28 docs: describe v2.2 with the swappable space section of the top plate
    v2.2 splits the top plate so only the space section is swapped
    (3-Split/6.25U and 5-Split parts are both included), without removing
    the plate or the TrackPoint flat cable. It ships in 3-Split, and the
    Mill-Max sockets v2.1 had at the 5-Split positions are dropped, so
    5-Split now needs soldered switches or user-installed sockets.
    Claude-Session: https://claude.ai/code/session_017n7xLjWUCbtMxuRRuscdiZ
2026-10-28 docs: make 3-Split the standard layout and finish the v2.2 notes
    v2.2 ships from 2026-10-28 in 3-Split Space, which is now the standard.
    The user guide, mouse manual, FAQ and firmware notes describe the
    3-Split bottom row first and note 5-Split differences; the layer
    diagrams use the 3-Split variant and the build-guide 3D figures are
    redrawn on the 3-Split scenes, with the swappable space part labelled
    in the exploded view. The five 5-Split positions without hot-swap
    sockets on v2.2 (Alt 1.5U, both mouse buttons, Space 1U, Delete 1.75U)
    are now named.
    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
